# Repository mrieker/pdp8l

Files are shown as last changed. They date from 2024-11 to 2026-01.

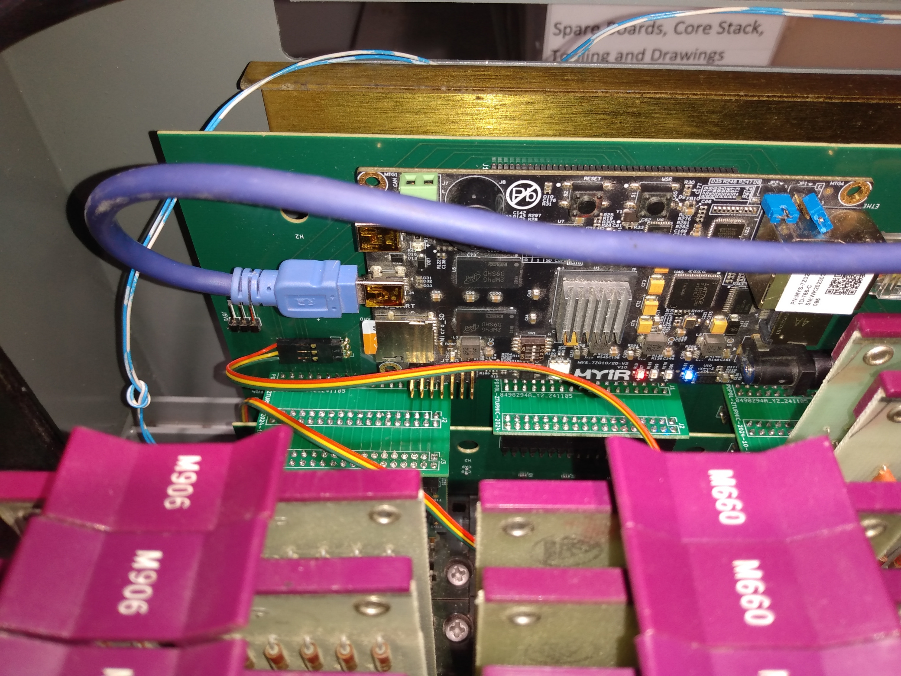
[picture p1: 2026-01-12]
pics/zturn-boards-installed-sideview.jpg

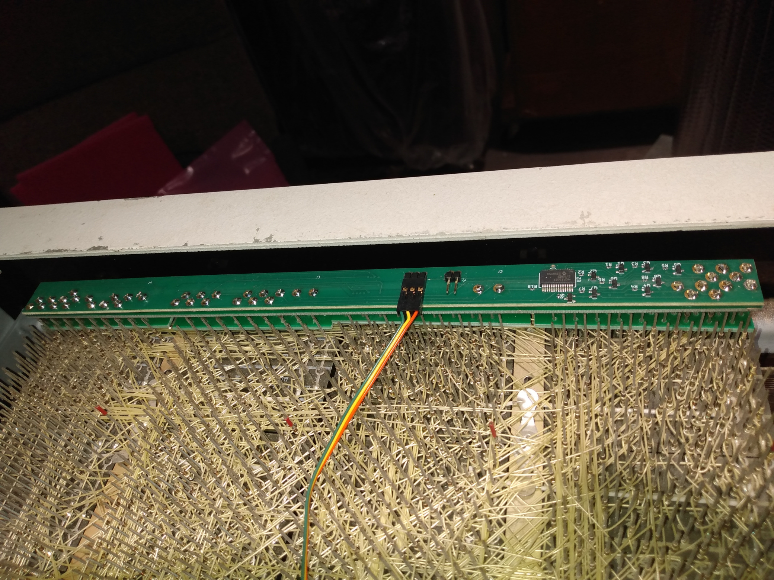
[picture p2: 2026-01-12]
pics/pcb4-installed-on-backplane.jpg

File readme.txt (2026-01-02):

PDP-8/L related projects

* automated front-panel replacement
    raspberry-pi based circuit board plugs in front slot
    raspi program runs TCL scripts to load and run tests (maindec and otherwise)

    pipan8l/pcb - circuit board
    pipan8l/pipan8l - raspi program
        provides TCL commands to access light & switch signals

* automated front-panel overlay
    I2C based circuit board piggy-backs onto row 1 of backplane with real panel plugged into slot 1
    connects to zturn board plugged into row 36 via 3-wire I2C cable
    zturn program runs TCL scripts to load and run tests (maindec and otherwise)

    pipan8l/pcb3 - circuit board (through hole parts)
    pipan8l/pcb4 - circuit board (surface mount parts)
    pipan8l/z8lpanel - zturn program
        provides TCL commands to access light & switch signals
            senses lights and switches
            can also override switches for automated testing and booting

* expansion box replacement
    zynq/zturn-7020 based circuit board set (4) plugs in rear slots
    provides functionality of 28KW extended memory, rk05, tc08, ttys, vc8 i & e
    can also provide base 4KW memory or use real PDP-8/L 4KW core
    can run with real PDP-8/L or can simulate the PDP-8/L for development

    pipan8l/z8l* - various zynq programs
        with real PDP-8/L only
            z8lreal - set fpga to real (non-simulation) mode
            z8lpanel - access front panel overlay board
                provides TCL commands to access real pdp light & switch signals
                can override or just sense real switches
        with zynq PDP-8/L simulator only
            can run on zturn board by itself or with all boards plugged into real pdp
            z8lsim - set fpga to simulation mode
                provides TCL commands to access simulated light & switch signals
            z8ltrace - print simulation instruction trace
        runs with either real or simulated PDP-8/L
            z8lcmemtest - test dma access to PDP-8/L core and zynq fpga memories
            z8ldump - dump zynq registers
            z8lmctrace - print memory cycle trace
            z8lrk8je - access RK05 disk drives
            z8lsimtest - test PDP-8/L processor with random instructions and data
            z8ltc08 - access TU56 tape drives
            z8ltty - access tty 03,40,42,44,46 lines
            z8lvc8 - access VC8 I & E
            z8lxmemtest - test extended memory

    zturn/zturn{34b,34d,35,36} - circuit boards for rear slots
    zturn/zturnic - interconnects the three boards (3 needed)
    zynq - zynq fpga code
    zplin - zynq petalinux

    see quickstart.txt for example programs

* repo directories

    edu20c - edusystem basic
    edu25r - edusystem basic
    music - music program (also boots OS/8)
    zturn - various zturn circuit boards (plug into slots 34,35,36 of PDP-8/L)
            needed for I/O emulation
    zplin - zynq petalinux files
            needed to rebuild linux kernel for zturn board
    zynq - fpga source files

    pipan8l - C++ programs that run on a RasPI or ZTurn

    pipan8l/km-* - various kernel modules needed by the RasPI and ZTurn programs

    pipan8l/pcb - front-panel replacement board for console automation only
            through-hole parts
            use with RasPI (no I/O device emulation)

    pipan8l/pcb3 - front-panel backplane overlay board
            through-hole parts
            use with ZTurn for console automation and I/O device emulation
            build pipan8l programs with 'make FPPCB=3'

    pipan8l/pcb3x - front-panel backplane pin spacer/pin alignment board

    pipan8l/pcb4 - front-panel backplane overlay board
            surface-mount parts
            use with ZTurn for console automation and I/O device emulation
            build pipan8l programs with 'make FPPCB=4'

    pipan8l/pdp8v - link to PDP-8/V repo for assembler and linker programs

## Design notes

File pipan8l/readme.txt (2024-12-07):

The pipan8l program runs on a RasPI-Zero-W plugged into the pcb that
is then plugged into slot 1 of the PDP-8/L replacing its front panel.

RasPI-Zero-W uses /dev/i2c-1 to access the I2C bus going to the PCB.
Any RasPI that runs recent RasPI OS and has a 40-pin GPIO connector
should work, but I use a RasPI Zero because it is small, allowing me
to flip the processor over without any issue.

Here is a pic of everything running:

    https://www.outerworldapps.com/pdp8l-with-pipan8l.jpg

The PIPAN8L board is in the lower right corner plugged into the 8/L downside-up.
The PC screen on the left shows the pipan8l program on the lower terminal window
testing memory, with pipan8l -status running on the upper terminal window
continuously showing the status of the lights and switches

- - - - - - - - - - - - -

The PCB plugs into slot 1 of the PDP-8/L in place of the console.

    RasPI-Zero-W ./pipan8l  ==>  PCB MCP23017s  ==>  PDP-8/L slot 1  ==>  rest of PDP-8/L

The RasPI can be powered from its own USB cable or from the PDP's 5V supply.
To power it from the PDP, install the jumper on the right end of the PCB.
I use the USB power so I can turn the PDP off and the RasPI will not need rebooting.

BE SURE TO USE 1.4mm THICK PCB STOCK.  1.6mm WON'T FIT.  The Digital spec says
board thickness of their modules is 0.056", which is a hair thicker than 1.4mm.
Even at 1.4mm, it takes a little gentle tapping to get it plugged in, so maybe
1.2mm might be better.  But even Digital's modules can be tough to insert.

I've used 1.2mm on the zturn36 board and it seems to work and is still firm but fairly
easy to insert.

- - - - - - - - - - - - -

./pipan8l runs the test program.  (You can type ./pip then press tab).
It reads commands from the prompt and can run scripts written in TCL.
The commands echo the switches and lights:

    setsw <switchname> <value>      - sets switch to a value
    getsw <switchname>              - gets value of a switch
    getreg <registername>           - gets value of a register (light bulbs)

And there is a command used to flush series of setsw commands:

    flushit                         - writes out any pending switch changes to MCP23017s
                                    - sets up to read MCP23017s when needed

There are a couple utility commands:

    ctrlcflag                       - sense if control-C has been pressed, optionallly clearing it
                                    - used for test scripts
                                    - otherwise, two control-Cs will abort out of pipan8l

    assemop <mnemonic> <operand>    - assemble the given assembly language instruction
    disasop <opcode>                - disassemble the given opcode to assemly language

And the pipan8lini.tcl script adds some higher-level commands:

    assem <address> <mnemonic> <operand>    - assemble the instruction and deposit in memory
    disas <start> <stop>                    - disassemble the instructions in given memory range
    dumpit                                  - print out all registers and switches
    flicksw <switchname>                    - flick the given switch on then off
    loadbin <filename>                      - load the given bin file into memory
    octal <value>                           - print the given value as 4-digit octal number
    rdmem <address>                         - read memory location
    startat <address>                       - does load address followed by start
    stepit                                  - do a single step then dump switches & lights
    wrmem <address> <value>                 - write the given value to memory

Note:
    The command processor is a TCL interpreter, so all numbers default to decimal.
    Prefix numbers with a 0 if you want to input an octal number.
    Use the octal command to convert number to octal for printing.

So when it's all running, you can do commands like:

    ./pipan8l               ;# start it running
    assem 0200 isz 030      ;# input a simple test program
    assem 0201 jmp 0200
    assem 0202 iac
    assem 0203 jmp 0200
    disas 0200 0203         ;# print it out to verify it
    startat 0200            ;# start it running
    flicksw stop            ;# stop it wherever it is
    setsw step 1            ;# turn on the step mode switch
    stepit                  ;# single cycle and print lights & switches
    stepit
    stepit                  ;# ... 3 times
    setsw step 0            ;# turn single cycle off
    flicksw cont            ;# continue
    dumpit                  ;# see it running
    dumpit
    flicksw stop            ;# stop processor so we can access memory
    octal [rdmem 030]       ;# read the counter and print in octal
    startat 0200            ;# restart program

Logged into RasPI:

$ sudo apt install tcl-dev
$ make
    ...
$ ./pipan8l

          ST=F  AC=0.7777 MA=0.7240 MB=7777 IR=7  OPR  SR=0000 DFLD IFLD MPRT STEP

TCL scripting, do 'help' for pipan8l-specific commands
  do 'exit' to exit pipan8l
pipan8l> assem 0200 isz 030
pipan8l> assem 0201 jmp 0200
pipan8l> assem 0202 iac
pipan8l> assem 0203 jmp 0200
pipan8l> disas 0200 0203
0200  2030  ISZ   0030
0201  5200  JMP   0200
0202  7001  IAC
0203  5200  JMP   0200
pipan8l> startat 0200
pipan8l> flicksw stop
pipan8l> setsw step 1
pipan8l> stepit
          ST=E  AC=0.0000 MA=0.0030 MB=0000 IR=2  ISZ  SR=0203 DFLD IFLD MPRT STEP
pipan8l> stepit
          ST=F  AC=0.0000 MA=0.5027 MB=5747 IR=2  ISZ  SR=0203 DFLD IFLD MPRT STEP
pipan8l> stepit
          ST=F  AC=0.0000 MA=0.0200 MB=2577 IR=5  JMP  SR=0203 DFLD IFLD MPRT STEP
pipan8l> setsw step 0
pipan8l> flicksw cont
pipan8l> dumpit
  RUN     ST=F  AC=0.0003 MA=0.4230 MB=5755 IR=3  DCA  SR=0203 DFLD IFLD MPRT
pipan8l> dumpit
  RUN     ST=E  AC=0.0005 MA=0.0100 MB=4177 IR=2  ISZ  SR=0203 DFLD IFLD MPRT
pipan8l> dumpit
  RUN     ST=F  AC=0.0006 MA=0.0233 MB=0560 IR=3  DCA  SR=0203 DFLD IFLD MPRT
pipan8l> flicksw stop
pipan8l> octal [rdmem 030]
4521
pipan8l> startat 0200
pipan8l>

- - - - - - - - - - - - -

It is somewhat tedious to keep entering dumpit commands to see what the panel is doing.
So pipan8l can be passed the -status option, and it will continuously dump the panel
contents in similar format to the actual PDP-8/L panel:

  PDP-8/L       -   - - -   - * -   - * *   - * -  0.0232  MA   IR [ - * *  DCA ]           1804 fps

                    * - -   * - *   * - *   - * -    4552  MB   ST [ f E d wc ca b ]

                -   - - -   - * *   - * -   - * -  0.0322  AC   ion per prt RUN

  MPRT  DFLD IFLD   - - -   - * -   - - -   - * *    0203  SR   ldad  start cont stop step exam  dep

Capital letters indicate the light is ON.
Small letters incdicate it is off.
Also, the ON lights are highlighted in green.

Leave pipan8l running in one terminal window of the RasPI.

Then, you can either run pipan8l -status from another terminal window of the RasPI:

    ./pipan8l -status

Or you can run it from a terminal window of a PC:

    ./pipan8l -status <ip-address-of-raspi>

It does UDP to the pipan8l program to read the panel state as fast as it can.

- - - - - - - - - - - - -

There is a simple memory test script, testmem.tcl.
To use it:

    ./pipan8l

    source testmem.tcl

    testzeroes 0 077            ;# test writing zeroes to memory 0000..0077
                                ;# writes then verifies

    testrands 0100 0177         ;# writes random numbers to 0100..0177 then verifies

    looptest testrands          ;# writes random numbers to 0000..0037 then verifies
                                ;#  then does 0040..0077 and verifies
                                ;#  then does 0100..0137 and verifies
                                ;#      ...
                                ;#  all the way through to 7740..7777
                                ;#  then repeats forever

Note:
    These tests run by simulating deposit and examine console operations so do not require that
    the processor be able to run a program.  It is just like someone manually doing load address,
    deposit and examines, flicking switches and reading lights, but it's all automated.

    The PDP-8/L circuitry limits the rate of panel operations (load address, examine, deposit, etc)
    to about 10 per second (for switch debouncing).  So these tests run S-L-O-W-L-Y.  But it beats
    doing it by hand!

$ ./pipan8l

TCL scripting, do 'help' for pipan8l-specific commands
  do 'exit' to exit pipan8l
pipan8l> source testmem.tcl

  looptest - wrap one of the below test to run continuously
  testzeroes [beg [end]] - writes zeroes to all memory then verifies
  testones [beg [end]] - writes ones to all memory then verifies
  testrands [beg [end]] - writes randoms to all memory then verifies

pipan8l> looptest testrands

PASS 1

write randoms 0000..0037...
 0000
verify randoms...
 0000: 5476       0453       6021       3630       3042       7403       7603       7006      
 0010: 6343       2240       0554       5052       6070       4357       0443       1714      
 0020: 4525       2447       5673       5475       5153       7647       4334       4777      
 0030: 3427       5527       0065       0560       4074       4412       6431       2176      
write randoms 0040..0077...

verify randoms...
 0040: 6633       5621       7064       6502       4116       5460       6045       5404      
 0050: 2353       3512       1610       4655       7162       1455       0204       2604      
 0060: 6124       4103       6756       5633       3630       1045       0376       2535      
 0070: 6567       0310       5311       3551       4376       6131       6133       2620      
write randoms 0100..0137...
 0100
verify randoms...
 0100: 7356       6277       7265       5057       4612       2453       7610       5016      
 0110: 2501       1631       1034       3662       6530       6421       7232       5563      
 0120: 6133       7601       2607       0475       5310       1223       0230       0133      
 0130: 3302       1425       2162       0576       5154       3105       0162       0132      
write randoms 0140..0177...

verify randoms...
 0140: 6554       3664       2233       0117       0740       4636       3725       7377      
 0150: 7375       3102       3445       3022       6025       4306       6576       4673      
 0160: 2404       7613       1611       3307       2613       1267       3407       2102      
 0170: 1546       5553       2043       5753       4444       0007       6152       2125      
write randoms 0200..0237...

Here is example output with a broken memory:

verify randoms...
 0000: 7732       5502       0231!=1771 7464       3560       1064       5730       2377      
 0010: 7375       4246       1242!=1666 3224       4575       1537       3413       1176      
 0020: 7073       3573       0006!=1027 1612       0216       0744       2370       3205!=3204
 0030: 1007       5501       2044!=7144 7655       5171       6066       3023       2437      
 0040: 6355       4405       2353!=2757 6220       0563       6101       7601       6625      
 0050: 7147       3323       2014!=3614 3347       4360       5405       2725       0326      
 0060: 6773       6361!=2360 2757!=0714 7663       6745       6574       4167       0760      
 0070: 3444       2046       1104!=3104 2461       1606       7437       2360       4746      
 0100: 2425       0710       4006!=7327 0163       6610       7104       2370       3022      
 0110: 0246       1307       2014!=3515 3146       7261       0212       1023       5405      
 0120: 1526       1515       4102!=4123 3770       1405       0464       3416       2317!=2316
 0130: 0432       2531       5246!=5756 0713       4227       5537       0561       7164      
 0140: 0735       7736       0110!=3314 0066       5141       0377       6707       4753      
 0150: 6760       6203       1025!=3025 3551       5451       5634       7334       4476      
 0160: 7416       6567!=4567 7757!=7756 1442       7417       2605       1020       6734      
 0170: 3106       1414       0137!=0537 5142       2133       2045       3725       4332      
 0200: 3162       1570       0000!=0212 5752       3554       1153       4414       1204      
 0210: 3345       2605       0000!=3200 0417       5403       0227       1676       3160      
 0220: 5074       2470       0006!=6617 2367       3341       3555       5204       2455      
 0230: 1016       5226       2401!=2621 6533       3131       7554       1325       1741      
 0240: 6507       0162       0001!=2373 5762       1014       6243       7537       1353      
 0250: 7167       2177       0020!=0023 4406       7050       0275       0236       5150      
 0260: 7351       5001!=5000 4651!=4251 1177       1361       5122       6003       2647      
                                    ^ shorted diode                                        ^ bad inhibit driver resistor
                         ^ shorted diode

- - - - - - - - - - - - -

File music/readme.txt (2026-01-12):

setup os/8 disk:

    ./setup-os8.sh      just once or to start over

boot os/8 disk:

    ./manual.sh real    using real pdp
    ./manual.sh sim     using simulator

compile music.pa (just once after doing setup-os8.sh):

    on another screen do: ./ldptr.sh music.pal

    then back on os/8 screen, press enter at ^ prompt:

        .R PIP
        *MUSIC.PA<PTR:
        ^

    press enter and tape reads in, then press control-C at * prompt:

    then you get . prompt:

        .PAL MUSIC,RKB0:MUSIC<MUSIC  (creates listing file, takes about 90 sec)
          or
        .PAL MUSIC<MUSIC             (no listing file, takes about 30 sec)

        .LOAD MUSIC
        .SAVE SYS MUSIC=2401         (creates SYS:MUSIC.SV file)

list music files and play something:

    .DIR RKB0:*.MU

    .R MUSIC
    *RKB0:FIFTH1
    (takes 5..10 sec then starts)
    control-Q to quit whatever it is playing and get * prompt for another file to play

to convert a midi file (4 tracks max):

    ./readmidi < somefile.midi > somefile.mu.txt
    ./ldptr.sh somefile.mu.txt

    .R PIP
    *RKB0:SOMEFL.MU<PRT:
    ^ enter
    * control-C

to hear music:

    real pdp only:
        tune radio 600..700kHz placed near backplane with cover off

    real pdp or sim (zturn plugged into pdp backplane with real pdp turned on):
        hook wire from D36-B2 backplane to amplified speakers
            open-collector so needs 3K-5K pullup to +5V such as on D36-A1

    real pdp or sim (zturn plugged into pdp backplane or not):
        run '../pipan8l/z8lpbit -server &' on a Linux PC or RasPI with headphones or speaker
            adjust volume with PC/RasPI sound control panel
        run '../pipan8l/z8lpbit -sound <ipaddressofpc> &' on the zturn

    sim only (zturn not plugged into pdp backplane):
        connect wire from zturn J11-26 to amplified speakers
        3.3V totem pole, do not use a pullup

to see it counting through the music:

    ../pipan8l/z8ldump

    look for xbraddr (extended block ram address) register
    should be able to see it count up as music plays

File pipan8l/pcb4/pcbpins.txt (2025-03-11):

AA1 SW MPRT     A28
AB1 SW DFLD     A27
AC1 SW IFLD     B28
AD1 SW SR04     A26
AD2 SW SR03         A01
AE1 LT LINK     A25
AE2 SW SR02         A02
AF1 LT EMA      A24
AF2 SW SR01         A03
AH1 LT MB01     A23
AH2 SW SR00         A08
AJ1 LT MA01     A22
AJ2 LT AC00         A04
AK1 LT AC03     A21
AK2 LT MB00         A05
AL1 LT AC02     B27
AL2 LT AC01         A06
AM2 LT MA00     A07
AN2 LT MB02         B01
AP2 LT MA02         B02
AR2 LT MB03         B03
AS2 LT MA03     B26
AT2 LT MB04         B04
AU2 LT MA04     B25

BD2 LT AC04     B24
BE2 LT AC05         B05
BF2 LT MB05     B23
BH2 LT MA05         B06
BJ2 LT AC06     B22
BK2 LT AC07         B07
BL2 LT MB06     B21
BM2 LT MA06         C01
BP2 LT MA07         C02
BR2 LT MB07         C03
BS2 LT MB08     C27
BT2 LT MA08     C26
BU2 LT AC08     C25
BV2 LT AC09     C24

CD1 LT MB09     C22
CD2             C23
CE1 LT MA09     C21
CE2 SW SR09     C28
CF1 LT AC11     D27
CF2 SW SR10         B08
CH1 LT AC10     D26
CH2 SW SR08         C04
CJ1 LT MA10     D25
CJ2 SW SR07         C05
CK1 LT MB10     D24
CK2 SW SR06         C06
CL2 SW SR05         C08
CM1             D23
CM2 LT MB11         C07
CN2 LT MA11         D01
CP2 LT FET          D02
CR2 LT IR00         D03
CS2 LT ION          D04
CT2 LT PARE         D05
CU1             D22
CU2 LT EXE          D06
CV2 LT IR01         D21
CV2 LT IR01         D07

DB1             C21
DD2 LT IR02         E01
DE2 LT DEF      E27
DF2 LT PRTE         E02
DH1             E26
DH2 LT RUN          E03
DJ1             E25
DJ2 LT WCT          E04
DK2 LT CAD      E24
DL2 LT BRK          E05
DM2 SW SR11         E06
DN1 SW BNCY     E23
DN2 SW STOP     E22
DP2 SW CONT         E07
DR2 SW STRT     E21
DS2 SW LDAD         E08
DT2 SW STEP     E28
DU2 SW EXAM         D08
DV2 SW DEPO     D28

U1-1	SR00
U1-2	SR03
U1-3	SR02
U1-4	SR01
U1-5
U1-6
U1-7
U1-8
U1-21
U1-22
U1-23
U1-24	MPRT
U1-25	IFLD
U1-26	LINK
U1-27	SR04
U1-28	DFLD

U2-1	RSR04
U2-2	RDFLD
U2-3	RIFLD
U2-4	RMPRT
U2-5
U2-6
U2-7
U2-8
U2-21	SR10
U2-22	RSR09
U2-23	SR09
U2-24	RSR10
U2-25	RSR02
U2-26	RSR01
U2-27	RSR00
U2-28	RSR03

U3-1	SR06
U3-2	EXE
U3-3	SR08
U3-4	ION
U3-5	SR07
U3-6	IR01
U3-7	SR05
U3-8
U3-21	IR00
U3-22	RSR05
U3-23
U3-24	PARE
U3-25	RSR08
U3-26	RSR06
U3-27	FET
U3-28	RSR07

U4-1	LDAD
U4-2	BNCY
U4-3	CONT
U4-4	SR11
U4-5	STEP
U4-6	EXAM
U4-7	DEPO
U4-8	RSTEP
U4-21	STOP
U4-22	IR02
U4-23	PRTE
U4-24	DEF
U4-25	CAD
U4-26	STRT
U4-27	WCT
U4-28	RSR11

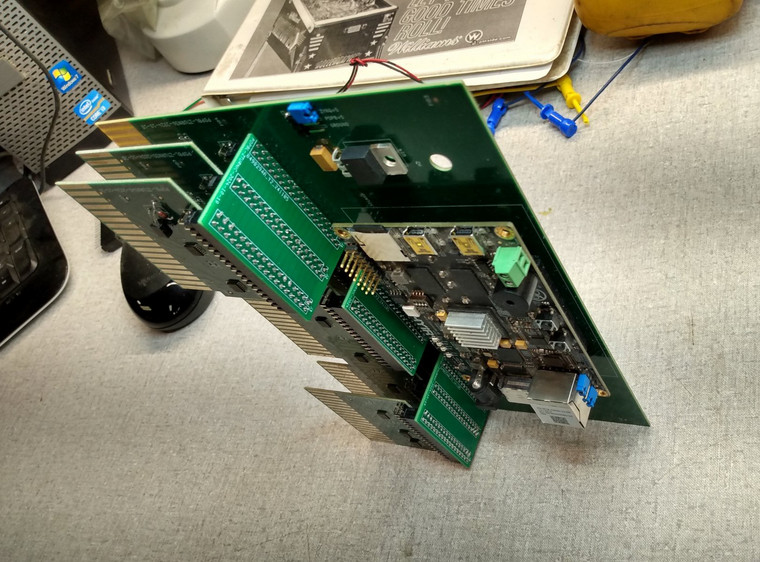
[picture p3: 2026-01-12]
pics/zturn-boards-alone.jpg

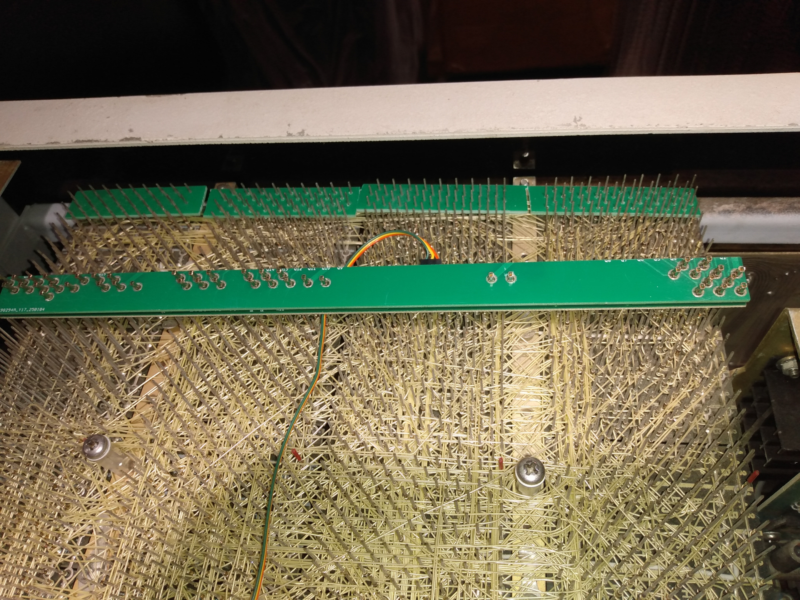
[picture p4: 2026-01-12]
pics/pcb4-removed-from-backplane.jpg

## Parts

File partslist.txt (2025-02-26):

    ZTURN36

        3) 2x18 pin 0.1" male horizontal
            https://www.digikey.com/en/products/detail/adam-tech/PH2RA-36-UA/9830520

        2) 2x40 pin 0.05" male
            https://www.digikey.com/en/products/detail/chip-quik-inc/HDR127MET80M-G-V-TH/9835079

        1) ZTurn 7020 (7010 has fewer I/O pins so won't work)
            https://www.myirtech.com/list.asp?id=502
                MYS-7Z020-C-S (no accessories) or MYS-7Z020-C (with accessories)
            accessories not strictly needed for the project but nice to have to run zturn by itself
            you will need a mini USB cable (for the console) and an ethernet cable

        2) 1x3 pin 0.1" male horizontal
            J5V1 - power jumper, 3 options:
                a) if ZTurn powered from its own USB or barrel connector, leave this empty
                   - this is useful to leave ZTurn running when PDP is turned off
                b) to power the ZTurn from the PDP8, jumper ZYNQ+5 to PDP8+5
                   - this eliminates need for ZTurn power supply
                c) power the ZTurn from some external supply using the GROUND and ZYNQ+5 pins
            JI2C1 - I2C connector going to PIPAN8L/PCB3 board
            https://www.digikey.com/en/products/detail/sullins-connector-solutions/QPC02SXGN-RC/2618262
            https://www.digikey.com/en/products/detail/w%C3%BCrth-elektronik/61300611021/4846832

        R1 - omit (pullup for B36-V1 spare zynq-to-pdp)
        R2 - omit (pullup for D36-B2 spare zynq-to-pdp - currently sound output)
        R4 - omit (pullup for I2C clock but can go on front panel board)
        R5 - omit (pullup for I2C data but can go on front panel board)

    ZTURN35

        3) 2x18 pin 0.1" male horizontal
            https://www.digikey.com/en/products/detail/adam-tech/PH2RA-36-UA/9830520

        R1 - required 1K 1/8W pullup for _EMA zynq-to-pdp

    ZTURN34D

        1) 2x18 pin 0.1" male horizontal
            https://www.digikey.com/en/products/detail/adam-tech/PH2RA-36-UA/9830520

        R3 - required 1K 1/8W pullup for B_RUN pdp-to-zynq
        C1 - 0.1uF 10V

    ZTURN34B

        1) 2x18 pin 0.1" male horizontal
            https://www.digikey.com/en/products/detail/adam-tech/PH2RA-36-UA/9830520

    ZTURNIC (3 needed, 2 with 3 connectors, 1 with 2 connectors)

        8) 2x18 pin 0.1" female
            https://www.digikey.com/en/products/detail/te-connectivity-amp-connectors/1-534998-8/291352

    PIPAN8L/PCB3

        J6 - 1x2 pin 0.1" male horizontal
             jumper for +5 to power MCP23017s from PDP
            https://www.digikey.com/en/products/detail/sullins-connector-solutions/QPC02SXGN-RC/2618262

        J7 pins 13,14,15 - 1x3 pin 0.1" male horizontal
                           I2C connector to go to ZTURN36 board
            https://www.digikey.com/en/products/detail/w%C3%BCrth-elektronik/61300611021/4846832

        43) backplane connector pins
            https://www.digikey.com/en/products/detail/te-connectivity-amp-connectors/1-104480-3/1125620

        Q1-Q16 - 2N3906 TO-92
            https://www.digikey.com/en/products/detail/onsemi/2N3906BU/1414

        U1-U4 - MCP23017 DIP package
            https://www.digikey.com/en/products/detail/microchip-technology/MCP23017-E-SP/894272

        C2,C3,C4,C5 - 0.1uF 10V
        C6 - 10uF 10V
        R22, R23, R24 - 2.2K 1/8W
        R1-R16 - 4.7K 1/8W

    Also needed is a 3-wire cable with 0.1" female header ends for the I2C going between
    the ZTURN36 board and the front panel piggy back board.  30" long is plenty.

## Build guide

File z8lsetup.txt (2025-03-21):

= = = = = = = = = = = = = = = =

Setting up the software and test software on simulator
Requires a ZTurn 7020 board but does not need to be plugged into PDP

    1) make SD card using procedure in zplin/quicksdcard.txt
       do not need to plug zturn into pdp-8/l yet

       there are BOOT.BIN and image.ub files in the zynq directory
       to copy to the SD card /boot directory

       there is a copy of the linux kernel headers in the zplin directory
        ...that are needed to build the kernel module

       the basic outline is (all done on a PC):
        1) put RasPI OS on an SD card
        2) delete all RasPI /boot files then replace with BOOT.BIN and image.ub
        3) expand rootfs partition to fill SD card
        4) edit SD card /etc/passwd to remove root and pi passwords
        5) put linux kernel headers on SD card /usr/src and link to /lib/modules

    2) plug USB cable from connector right next to the SD card on ZTurn card to a PC
       ...this is the console
       use a com port program to access the serial port at 115,200 baud

    3) log in as root to set up network and install some utilities
       - look for apt installs in zplin/quicksdcard.txt
       - enable ssh daemon and set passwords so ssh will work

    4) use ssh to log into the ZTurn as non-priv user (pi)
       optionally copy PC's .ssh/id_rsa.pub to ZTurn's .ssh/authorized_keys using scp so you don't need password any more
       clone the repo either from the PC or from github

        git clone https://github.com/mrieker/pdp8l.git

    5) download some maindec files

        cd pdp8l
        wget https://pdp8online.com/ftp/software/paper_tapes/tapes.tgz
        tar xzvf tapes.tgz

        ...should create a directory called alltapes

        wget https://so-much-stuff.com/pdp8/tapes/maindec/maindec-08-d3ra-pb -O alltapes/d3ra-pb.bin

    6) compile the software on the ZTurn

        cd pipan8l
        make FPPCB=3    have the through-hole part front panel board
        make FPPCB=4    have the surface-mount part front panel board

    7) should be able to run a couple maindecs on simulator:

        ./z8lsim run-d01b.tcl
        ./z8lsim run-d02b.tcl

    8) compile and run demo programs on simulator:

        git clone https://github.com/mrieker/pdp8v.git
        cd pdp8v/asm
        make
        cd ../..

        ./z8lsim doubleroll.tcl
        - uses './z8lsim -status' to display ascii-art front panel
        - MA & AC lights roll in opposite directions
        - press control-C to abort

        ./z8lsim kaleid.tcl e
        - displays random patterns in simulated VC/8E X window
        - close X window or press control-C to abort
        - have to use ssh -X from PC so it can open window

    9) run music program on simulator

        cd ../music
        more readme.txt
        - follow instructions therein

= = = = = = = = = = = = = = = =

Getting it to work on real PDP-8/L:

    1) plug all circuit boards in, including front panel piggy back
       should put power jumper plug on front panel piggy back board
       zturn36 board should not have a power jumper because the console usb will supply power

       Note:
        You will need to remove boards from rows 31,32,33 to get these boards
        plugged in.  Then plug them back in, subject to the TTY note below.

        Be very careful when plugging in the interconnect connectors, it is very
        easy to be off-by-one.  Maybe use a dental mirror to inspect before
        powering on.

        Likewise it is very easy to be off-by-one when plugging the ZTurn card
        into the ZTURN36 board with those finely spaced pins so be sure they are
        in correctly before powering on or it might fry some Zynq chip driver
        transistors.  And make sure the ethernet connector is where the ZTURN36
        board says ETHERNET.

       Note:
        The test programs use the TTY circuits in the FPGA to access TTY input/
        output so you must remove the TTY boards M706 and M707.  You can also
        remove the TTY clock gen card M452 and TTY cable card W076.

        When not running tests, such as when running OS/8, the FPGA TTY can be
        accessed using the ./z8ltty command.  Or you can plug the TTY boards
        back in and use them.

    2) hook up ethernet and console USB cables to the ZTurn

       Note:
        If the ZTurn has a static IP address, you should not need the USB cable
        except to power the ZTurn board.  Alternatively, the ZTurn can be powered
        from the PDP via the power jumper on the ZTURN36 board.  It is probably
        not a good idea to have both the USB cable connected and the power jumper
        in place at the same time.

    3) should still be able to log in just as before and simulator should still work

    4) turn PDP-8/L on

    5) from pdp8l/pipan8l directory

    * Test I2C connection to front panel

        ./i2cztest
        - press control-C to abort

    * Run basic memory test (analogous to toggling various locations via front panel switches):

        ./z8lreal                       # make sure accessing real PDP (not sim)

        ./z8lpanel                      # access front panel piggy-back board for automated testing

        ;# these commands override the real switches to do ldad, exam, dep to access single memory locations
        ;# should see lights blink as each deposit/examine is done
        ;# processor must be halted for them to work (just like doing ldad, exam, dep from front panel)
        ;# ...and should remain halted throughout

        z8lpanel> wrmem <addr> <data>   ;# write <data> to memory at <addr> (it's TCL so need leading 0 for octal)
        z8lpanel> octal [rdmem <addr>]  ;# read memory at <addr> then display in octal

            ;# they can be scripted, eg, to repeatedly write 5432 to mem addr 12345 until control-C:
            z8lpanel> while {![ctrlcflag]} {wrmem 012345 05432}
            ;# ... then you can trace through with a scope

            Note:
                The rdmem and wrmem commands can only access addresses 000000..017777 because the PDP-8/L
                panel only has switches for that address range.

        ;# access some memory test scripts (they use rdmem, wrmem to access memory)

        z8lpanel> source testmem.tcl

        ;# tests use console deposit/examine so they run s-l-o-w-l-y
        ;# press control-C once to abort a test back to z8lpanel> prompt
        ;# ... twice quickly should get to shell prompt

        z8lpanel> testzeroes 0 077      ;# writes 0s to locations 0000..0077 then verifies (use other ranges as needed)
        z8lpanel> testones 0 077        ;# writes 1s to locations 0000..0077 then verifies (use other ranges as needed)
        z8lpanel> looptest testrands    ;# writes random numbers to memory then verifies, in blocks of 64 words at a time

        z8lpanel> isziactest            ;# puts a simple ISZ/IAC loop in memory
        z8lpanel> startat 020           ;# start it running
                                        ;# should see link,accumulator incrementing on front panel
        z8lpanel> octal [getreg ac]     ;# read AC via D connectors at back of PDP then display in octal
        z8lpanel> dumpit                ;# dump all front panel values, observe RUN indicator
        z8lpanel> flicksw stop          ;# stop the test (optional), or use front panel stop switch
        z8lpanel> dumpit                ;# dump all front panel values, RUN indicator absent
        z8lpanel> exit

      Note:
        The above tests are generally sufficient to see if the PDP is working.  The memory tests
        will find stuck memory bits and stuck MA/MB register bits, and isziactest will test that
        the processor can execute instructions and that the AC does not have stuck bits.

      Note:
        Run './z8lpanel -status' from another ssh window to see an ascii-art replica of
        the front panel continuously updated while running the above tests.  It should
        match what the real PDP lights are showing.  If not, there is a problem, might
        be as simple as a burnt out bulb.  The AC,MA,MB,RUN,BREAK signals are read from
        the row 34,35,36 connectors at the back so that might be another source of error.

        The switch register will be different because the tests tell z8lpanel to
        override the real switches.  In any case, './z8lpanel -status' will show what
        the PDP actually sees for switches.  Use the 'relsw all' command in z8lpanel
        to release its override of the switches.  Using 'setsw sr 01234' tells z8lpanel
        to override the switchregister switches with 1234.

      Note:
        The above tests also work with z8lsim (although much faster).

      Note:
        If your core memory has issues, the FPGA can handle the core functionality.
        Instead of './z8lreal' command, use './z8lreal -enlo4k' (enable low 4K FPGA memory).
        The FPGA will tell the PDP to use FPGA RAM for all memory accesses by holding _EA low.
        You can verify enlo4k mode with either './z8ldump -once' from shell or
        'pin get xm_enlo4k' from within z8lpanel.

        You can also turn it on from within z8lpanel with 'pin set xm_enlo4k 1'
        and turn it off with 'pin set xm_enlo4k 0'.  Processor should be halted
        while using these commands!  Try 'hardreset' command if PDP gets jammed
        up somehow.

    * Test ZTurn bus connections (tests abort if they find an error):

        If your PDP does not have the DMA (BREAK) option installed,
        use the './z8lreal -nobrk' command to tell FPGA to not use
        it.  The FPGA will use internal circuitry to access its own
        RAM, even for the low 4K, instead of trying to use the PDP's
        DMA option circuitry.  This option also forces enlo4k mode
        so the processor will always use the FPGA RAM even for the
        low 4K.  This setting is also available in z8lpanel as the
        cm_nobrk pin, but you must also explicitly turn on enlo4k
        mode with pin xm_enlo4k, 'pin set xm_enlo4k 1 cm_nobrk 1'.

        memory (B) connectors - get memory address (MA) from the PDP
                                send memory read data (MEM) to the PDP
                                (write data is on MB register lines)
        dma (C) connectors - send DMA address and write data to the PDP
                             (read data is on MB register lines)
        pio (D) connectors - get memory buffer (MB) from the PDP
                             get accumulator (AC) from the PDP
                             send PIO read data (INPUTBUS) to the PDP

        test dma (C) and memory (B) connectors:
            ./z8lcmemtest
            - prints 'pass m complete n errors' (2 or 3 sec)
            - press control-C to abort

            ./z8lcmemtest -3cycle -cainc -extmem
            - tests all the bells and whistles (15 to 20 sec per pass)

            The panel lights should show a constant 5252 for MA and MB
            and that the processor is running FETCH cycles.  Theoretically
            you could see a glow of the BREAK light along with fainter
            WC and CA lights but it may not be apparent.  You can see those
            other state occasionally on the ./z8lpanel -status display when
            it happens to sample the lights at just the right time.

            Basically the processor is executing a '5252: JMP 5252' instruction
            while the z8lcmemtest program is making like it is a disk controller
            doing DMA requests via pdp8lcmem.v to read and write memory.

        test pio (D) connectors (assumes z8lcmemtest works):
            ./z8lpiotest
            - prints '*' after each pass (2 sec or so at first then every 0.5 sec thereafter)
            - press control-C to abort

            There should be a glow of activity on the front panel for
            this test as the processor is running a little program that
            can be found in z8lpiotest.cc.

        pound the living daylights out of it (originally for testing sim but adapted to test real PDP):
            ./z8lsimtest -real                      # prints every insruction
            ./z8lsimtest -real | grep '0000  L'     # prints every 10000th instruction

            You will have to get things started manually or use z8lpanel in a separate screen.
            Start the test then follow the prompt to get things going.  It waits for you to
            stop the processor, then enter the '5252: JMP 5252' loop and start it.  Either use
            the front panel directly or use z8lpanel from another ssh screen:

                ./z8lpanel
                z8lpanel> flicksw stop
                z8lpanel> setsw sr 05252
                z8lpanel> flicksw ldad
                z8lpanel> flicksw start
                z8lpanel> relsw all
                z8lpanel> exit

            It stops if there is any error.  It should run as long as you want it to.

            All lights should be flashing randomly as z8lsimtest feeds the PDP random instructions
            and operands, verifying each memory cycle as it goes along.  Also feeds in DMA cycles
            here and there (1-cycle and 3-cycle) and interrupt requests.  You shouldn't see any
            activity on the PAR,PROT lights and ION will just occasionally blink.  Also rare is for
            any of the WC,CA,B lights to blink, and RUN should be on continuously.

            Then maybe show lights in ascii-art screen while test is running:
                ./z8lpanel -status

        Note:  It is possible for these tests to leave the PDP in a wacky state when
            stopped (with control-C).  Try the 'hardreset' command in z8lpanel to try
            to unjam it, or as a last resort, power cycle the PDP.

    * Run MAINDECs:

        note:
            the loadbin function runs a lot slower on the real machine vs the simulator
            it uses deposit/examine to load the program in memory which is slow on real PDP-8/L

        ./z8lpanel run-d01b.tcl
        ./z8lpanel run-d02b.tcl
        ./z8lpanel run-d04b.tcl
        ./z8lpanel run-d05b.tcl
        ./z8lpanel run-d07b.tcl
        ./z8lpanel run-d1eb.tcl
        ./z8lpanel run-d1gb.tcl
        ./z8lpanel run-d3ra.tcl

        note:
            when running d3ra test, you may want to monitor dectape status in another
            ssh window with a './z8ltc08 -status' command (another ascii-art screen)

    * Run doubleroll, kaleidoscope and music programs as desired

        Use same instructions as for simulator except do a ./z8lreal
        command to make sure using real PDP, then use ./z8lpanel instead
        of ./z8lsim.

= = = = = = = = = = = = = = = =

    To monitor what is going on with the FPGA at any time, run the ./z8ldump program.
    It is a continuous dump of all the registers the FPGA makes available to the ARM processor.
    It can be run at any time without any side effects.
    It is often useful to leave ./z8ldump running on one window all or most of the time.
    You can do './z8ldump -once' to just display one frame.

    Sample output:

        VERSION=384C4097 8L
          oBIOP1=0             oBAC=0000                              iBEMA=1              iDMAADDR=2540     S majstate=HALT
          oBIOP2=0             oBMB=7572           nanocstep=1        i_CA_INCRMNT=1       iDMADATA=1175     I nextmajst=HALT
          oBIOP4=0             oMA=2420            nanotrigger=1      i_DATA_IN=1          iINPUTBUS=0000    M timedelay=0
          oBTP2=0                                  nanocontin=1       iMEMINCR=0           i_MEM=0205        . timestate=TSIDLE
          oBTP3=0            S lbBRK=0             fpgareset=0        i_MEM_P=1          S swCONT=0          . cyclectr=0000
          oBTS_1=0           I lbCA=0              simit=0            i3CYCLE=0          I swDEP=0           . simmemen=0
          oBTS_3=0           M lbDEF=0             bareit=0           iAC_CLEAR=0        M swDFLD=0
          o_BWC_OVERFLOW=1   . lbEA=0                                 iBRK_RQST=0        . swEXAM=0          S debounced=0
          o_B_BREAK=1        . lbEXE=0             bDMABUS=5104       i_EA=0             . swIFLD=0          I lastswLDAD=0
          oE_SET_F_SET=1     . lbFET=0             x_DMAADDR=0        iEMA=1             . swLDAD=0          M lastswSTART=0
          oJMP_JMS=0         . lbION=0             x_DMADATA=1        iINT_INHIBIT=0     . swMPRT=0
          oLINE_LOW=0        . lbLINK=0                               iINT_RQST=0        . swSTEP=0            oC36B2=0
          oMEMSTART=0        . lbRUN=0             bMEMBUS=7777       iIO_SKIP=0         . swSTOP=0            oD35B2=0
          o_ADDR_ACCEPT=1    . lbWC=0              r_MA=1             i_MEMDONE=1        . swSTART=0
          o_BF_ENABLE=1      . lbIR=2              x_MEM=1            i_STROBE=1         . swSR=0000
          o_BUSINIT=0
          oB_RUN=0           S lbAC=0000           bPIOBUS=7671       memcycctr=91D2492D   xbraddr=00000
          o_DF_ENABLE=1      I lbMA=0204           r_BAC=1            didio=0              xbrwena=0
          o_KEY_CLEAR=1      M lbMB=0337           r_BMB=0            hizmembus=1          xbrenab=0
          o_KEY_DF=1                               x_INPUTBUS=1       meminprog=   0       xbrrdat=7572
          o_KEY_IF=1           o_LOAD_SF=1                                                 xbrwdat=0000
          o_KEY_LOAD=1         o_SP_CYC_NEXT=1

        VERSION=524B2005 RK 00000000 00000000 00000000 00000000 00000001 DEADBEEF DEADBEEF

        VERSION=56432005 VC 00000000 30100000 00006996 203EBED8 DEADBEEF DEADBEEF DEADBEEF

        VERSION=4650200D FP 00000000 00000000 6B7FE97F 00F51FF2 F0009F30 00000000 DEADBEEF

        VERSION=584D202D XM  enlo4k=0  enable=1  ifld=6  dfld=6  field=6  _mwdone=1  _mrdone=1  os8zap=0,step=0
                mrhold,step=0,0  mwhold,step=0,0  xmstate= 0  xmmemenab=0  memcycctr=689F89F8.9D89F89F
                addrlatchwid=8  readstrobedel=35  readstrobewid=10  writeenabdel=75  writeenabwid=5  writedonewid=10

        VERSION=5348200C SH err=2000 foe=0 ms=F  ts=1+ 1 ir=5252 pc=5252 mb=5252 ma=5252 l.ac=0.0000 ea=5252

        VERSION=434D1018 CM 227D0560 00000020 00000000

        VERSION=54541009 TT 40000091 000000AA 00000103

        VERSION=54541009 TT 40000D5B 00000C80 00000120

        VERSION=54541009 TT 40000000 00000000 00000122

        VERSION=54541009 TT 40000000 00000000 00000124

        VERSION=54541009 TT 40000000 400006A3 00000126

        VERSION=50421004 PB 004AE000 30D30005 00000000

        VERSION=50520002 PR 00000000

        VERSION=50500001 PP 00000000

        VERSION=54430002 TC 80000000

  Top half (above the RK line):

    These signals top center are important:

        nanocontin=1        =1: FPGA is clocking itself at 100MHz (normal)
                            =0: FPGA must be clocked by setting nanotrigger (debugging)
        fpgareset=0         =0: FPGA running normally
                            =1: FPGA being held in power-on reset state
        simit=0             =0: FPGA is using real PDP-8/L (sim held in reset)
                            =1: FPGA is using simulator (ignoring PDP)
        bareit=0            =0: send simulated device signals to PDP (normal)
                            =1: send ARM debug signals to PDP (debugging)

        They can be read with ./z8lpanel 'pin get' command and written with 'pin set' command.
        The nanotrigger signal is self-clearing.

            pin set fpgareset 1 fpgareset 0     ;# blip the fpgareset signal
            pin get simit                       ;# see if simulating (prints/returns 0 or 1)
            pin set simit 1                     ;# turn on simulator (ignore PDP)

    Signals beginning with 'o' are outputs from the PDP to the FPGA.
    The names pretty much correspond with the signals in the PDP documentation.
    The ones that have o_ at the beginning are active low, the others are active high.

        oBIOP1 = I/O pulse 1 from the PDP (active high)
        o_B_BREAK = break cycle indicator from the PDP (active low)

    Signals beginning with 'i' are inputs to the PDP from the FPGA.
    The names pretty much correspond with the signals in the PDP documentation.
    The ones that have i_ at the beginning are active low, the others are active high.

        iBRK_RQST = FPGA is requesting a DMA cycle from the PDP (active high)
        i_EA = FPGA is telling PDP to use extended memory instead of core for the cycle (active low)

    Signals beginning with 'b' are the bi-directional busses, bPIOBUS (on the 'D' connectors),
    bMEMBUS (on the 'B' connectors), bDMABUS (on the 'C' connectors).  The bits are generally
    scrambled around so aren't generally useful.  The bus signals are gated between the FPGA
    and the PDP by the r_ (received into the FPGA from the PDP) and x_ (transmitted out from
    the FPGA into the PDP) signals.  Care must be taken to not enable two drivers on the same
    set of wires at the same time so the transistors don't get overloaded.

    Note:
        Active high/low of these signals may differ from the PDP-8/L signal as the signal
        may go through an inverting 3.3V/5V conversion between the FPGA and the PDP-8/L.

    Signals listed with S-I-M pertain to the simulator only.
    Those beginning with lb are lightbulbs, sw are switches.
    Others are miscellaneous state information.

  Bottom half (starting with RK line) are the device modules:
    Most are raw ARM 32-bit registers so are in hexadecimal

    RK - pdp8lrk8je.v module registers (decpack)

    VC - pdp8lvc8.v module registers (video controller)

    FP - pdp8lfpi2c.v module registers (front panel via I2C)

    XM - pdp8lxmem.v module registers (extended memory)

        of particular importance:

            enlo4k=1 : use FPGA 32KW memory for low 4K
                  =0 : real PDP-8/L : use PDP-8/L core memory for low 4K
                          simulator : use small FPGA 4KW memory for low 4K
            available to z8lpanel pin get/set command as xm_enlo4k

    SH - pdp8lshad.v module registers (processor shadow)

            monitors processor cycles to make sure they are what they should be
            sets err bits and freezes contents when discrepancy found
            works only when enlo4k enabled continuously since last START key

    CM - pdp8lcmem.v module registers (direct memory access)

            used by z8lrk8je and z8ltc08 to do dma transfers

        of particular importance:

            VERSION=434D1018 CM 227D0560 00000020 00000000
                                         ^
                                         |
                                         bit <29> = available to z8lpanel pin get/set command as cm_nobrk

            - cm_nobrk=0 : uses PDP's BREAK circuitry so can access PDP's core memory
            - cm_nobrk=1 : all accesses are made to FPGA's 32KW memory
                           must have xm_enlo4k set for it to be useful
                           otherwise PDP would be using its own core for low 4K,
                             while all low 4K DMA would be going to FPGA RAM

    TT - pdp8ltty.v module registers (teletypes)

        of particular importance:

            VERSION=54541009 TT 40000091 000000AA 00000103
                                                        ^^
                                                        ||
                                                        kb I/O port (+1 for the pr I/O port)

    PB - pdp8lpbit.v module registers (pulse bit audio)

    PR - pdp8lptr.v module registers (paper tape reader)

    PP - pdp8lptp.v module registers (paper tape punch)

    TC - pdp8ltc08.v module registers (dectape)

= = = = = = = = = = = = = = = =

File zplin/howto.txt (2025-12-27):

########################################################################
#  How to set up tools for building Zynq FPGA code and create SD card  #
########################################################################

note:
    to create an sd card with the given fpga code, follow steps in quicksdcard.txt.
    if you want to make changes to the fpga code, follow the steps below.

start with:
    always needed:
        ZTurn 7020 board
        raspberry pi os install image (32-bit lite version)
        - bookworm (debian 12) is slow, bullseye (debian 11) is fast
        - ref: https://forums.raspberrypi.com/viewtopic.php?t=6019 -- bug mentioned halfway down

    to compile FPGA code:
        ubuntu 16.04
        vivado 2018.3 installed in /tools/Xilinx/Vivado/2018.3/bin/vivado
        petalinux 2018.3 in /tools/Xilinx/Downloads/petalinux-v2018.3-final-installer.run
        ./zturn_7z020_hdmi.bsp
        ./vdmahdmi.patch

        also make sure board_files/zturn-7z020 is in place in vivado tree
            /tools/Xilinx/Vivado/2018.3/data/boards/board_files/zturn-7z020
        untar ./zturn-7z020-board-files.tgz if not there

        must use Vivado 2018.3 cuz of bsp file supplied by MYIR

##############################
#   build petalinux kernel   #
##############################

    This creates a new boot file with default FPGA code (BOOT.BIN) and kernel image (image.ub).
    You can skip this section and use the provided images in ../zynq/BOOT.BIN and image.ub.

sudo ...
    apt install tofrodos iproute gawk gcc git-core make net-tools ncurses-dev \
        libncurses5-dev tftpd-hpa zlib1g-dev flex bison lib32z1 lib32ncurses5 lib32stdc++6 libselinux1
    apt install build-essential
    apt install chrpath socat autoconf libtool texinfo gcc-multilib
    apt install libsdl1.2-dev libglib2.0-dev
    apt install openssl-dev
    apt install libssl-dev
    apt install openssl
    apt install zlib1g:i386

    dpkg-reconfigure dash      << select <No>

# https://www.instructables.com/Getting-Started-With-PetaLinux/

[[ do the whole thing from medium-sized xterm ]]

cd .../pdp8l/zplin              # ie, directory containing this howto.txt
/tools/Xilinx/Downloads/petalinux-v2018.3-final-installer.run `pwd`/petadevel   # 11m56
    q y <Enter> q y <Enter> q y <Enter>    to skip licenses

source petadevel/settings.sh
source /tools/Xilinx/Vivado/2018.3/settings64.sh

mkdir petakernl
cd petakernl
petalinux-create -t project -s ../zturn_7z020_hdmi.bsp  # 1m05
cd zturn
petalinux-config    # 1m35 (just select <Exit> at the bottom)
petalinux-build     # 5m44
petalinux-package --boot --force --fsbl ./images/linux/zynq_fsbl.elf --fpga ./images/linux/system.bit --u-boot

cd build/tmp/work-shared/plnx-zynq7/kernel-source
patch -p1 < ../../../../../../../vdmahdmi.patch
    to disable VDMA and HDMI  (don't have fpga source for hdmi stuff)

    - unpatched xilinx_vtc.c 20094 bytes
        patched xilinx_vtc.c 19220 bytes

cd ../../../../..               (ie, petakernl/zturn)

petalinux-config -c kernel
    Device Drivers --->
        DMA Engine Support --->
            Xilinx DMA Engines [off]
            Xilinx AXI DMAS Engine [off]
petalinux-build     3m36                            # let it fail to compile vdmafb.c

cd build/tmp/work-shared/plnx-zynq7/kernel-source
patch -p1 < ../../../../../../../vdmahdmi.patch     # second time
cd ../../../../..               (ie, petakernl/zturn)
petalinux-build     4m52                            # it should succeed

petalinux-build -c kernel -x compile -f             # 0m29
petalinux-build                                     # 1m57
petalinux-package --boot --force --fsbl ./images/linux/zynq_fsbl.elf --fpga ./images/linux/system.bit --u-boot
ls -l images/linux/BOOT.BIN                         # contains default FPGA code
ls -l images/linux/image.ub                         # linux kernel

if edit kernel sometime:
    petalinux-build -c kernel -x compile -f
    petalinux-build

###################
#  Set up SDCARD  #
###################

    Sets up SDCARD with the BOOT.BIN and image.ub suitable for the Zynq
    Uses raspi filesystem.

# put blank sdcard in pc, comes up as something like /dev/sda
# replace /dev/sda in the commands below with whatever the sdcard really is

df                  # see if sdcard got automounted
umount /dev/sda1    # umount if so
umount /dev/sda2 ...etc

# copy raspi sdcard image to sdcard
xzcat 2024-10-22-raspios-bullseye-armhf-lite.img.xz | dd of=/dev/sda status=progress
partprobe /dev/sda

# replace raspi kernel with zturn kernel
# - use either the BOOT.BIN,image.ub created above or use those from ../zynq directory
mkdir /x
mount /dev/sda1 /x
rm -rf /x/*
cp images/linux/BOOT.BIN /x/
cp images/linux/image.ub /x/
umount /x

# expand root partition to whole sdcard
parted /dev/sda
  resizepart 2 -1s
  quit
resize2fs /dev/sda2

# remove root and pi passwords for now
mount /dev/sda2 /x
edit /x/etc/shadow              (use whatever editor you like)
  remove * or ! from root and pi line password field

# set up hostname
echo zturn > /x/etc/hostname    (or whatever you want for hostname)
edit /x/etc/hosts
  change raspberrypi to whatever was put in /x/etc/hostname

# copy kernel source so modules will compile
mkdir -p /x/usr/src/linux-headers-4.14.0-xilinx-v2018.3
rsync -av petakernl/zturn/build/tmp/work-shared/plnx-zynq7/kernel-source/ /x/usr/src/linux-headers-4.14.0-xilinx-v2018.3
rsync -av petakernl/zturn/build/tmp/work-shared/plnx-zynq7/kernel-build-artifacts/ /x/usr/src/linux-headers-4.14.0-xilinx-v2018.3
chown root:root -R /x/usr/src

# done filling sdcard
umount /x       may take a long time to flush to sdcard (30min)
rmdir /x

############################
#  Boot ZTurn from SDCARD  #
############################

connect usb serial cable from pc to zturn (115200 baud) and use terminal program to access
insert sdcard and boot zturn
login as root (or as pi then sudo bash to get root)

on zturn:
  as root:
    raspi-config -> Interface Options -> SSH -> Yes
    passwd   to set root and pi passwords so ssh will work

    optionally set up static IP address:
      edit /etc/dhcpcd.conf
      uncomment static ip configuration section
      reboot

    apt install libreadline-dev
    apt install libx11-dev
    apt install tcl8.6-dev
    apt install git
    apt install bc

    mkdir -p /lib/modules/4.14.0-xilinx-v2018.3
    ln -s /usr/src/linux-headers-4.14.0-xilinx-v2018.3 /lib/modules/4.14.0-xilinx-v2018.3/build

    cd /usr/src/linux-headers-4.14.0-xilinx-v2018.3
    edit scripts/dtc/dtc-lexer.lex.c_shipped
      Find the line 'YYLTYPE yylloc;' and change it to 'extern YYLTYPE yylloc;'
      reference : https://lkml.org/lkml/2020/4/1/1206
    make oldconfig          # 0m38
    make prepare            # 0m31
    make modules_prepare    # 1m28

  as pi:
    git clone .../pdp8l.git
    cd pdp8l/pipan8l
    make   (may need to change -ltcl to -ltcl8.6 in the makefile)
    ./z8lsim
      if Bus error - means the BOOT.BIN has default FPGA contents so do next section
      if z8lsim> prompt - means our PDP-8/L code is loaded in FPGA
    z8lsim> source testmem.tcl
    z8lsim> looptest testrands
        ...  control-C to stop test
    z8lsim> exit

######################################
#  Put PDP-8/L FPGA file onto ZTurn  #
######################################

    make sure can do ssh root@zturn from pc

then on zturn:
    ls -l /boot should show BOOT.BIN, image.ub files

    # ls -l /boot
    total 8456
    -rwxr-xr-x 1 root root 4688040 Dec  5 22:43 BOOT.BIN
    -rwxr-xr-x 1 root root 3967676 Dec  5 22:43 image.ub

then back on pc to compile FPGA code:
    cd .../pdp8l/zynq
    /tools/Xilinx/Vivado/2018.3/bin/vivado pdp8l.xpr
        do 'Generate Bitstream' to compile verilog to .bit file
    ./makebootbin.sh        make BOOT.BIN then copy to zturn and reboot

then ssh pi@zturn and do:
    cd pdp8l/pipan8l
    ./z8lsim
      if Bus error - means the BOOT.BIN still has default FPGA contents
      if z8lsim> prompt - means our PDP-8/L code is loaded in FPGA
    z8lsim> source testmem.tcl
    z8lsim> looptest testrands
        ...  control-C to stop test
    z8lsim> exit

All Done!

#########################################
#  FYI, how to create a Vivado project  #
#########################################

Use Z-turnBoard_Tutorial_Book.pdf
    - make sure board_files/zturn-7z020 is in place in vivado tree
      eg, /tools/Xilinx/Vivado/2018.3/data/boards/board_files/zturn-7z020
    - in left column, "Create Block Design"
    - add ZYNQ7 Processing System
    - do "Run Block Automation" to define and connect DDR, FIXED_IO ports
    - interconnect clocks FCLK_CLK0 -> M_AXI_GP0_ACLK, S_AXI_HP0_ACLK
    - add any Verilog/VHDL files & add as modules to block diagram
        keep them in top-level directory so Vivado doesn't bury them
    - create hardware wrapper
        "Sources" tab
        right-click the .bd file
        select "Create HDL Wrapper"
        "Let Vivado manage..."
        OK

    - Run Synthesis, but then do "Open Synthesized Design"
        - Window -> I/O Ports
        - Scalar ports
        - make pin assignments
        - click save (floppy) button in upper left to save as constraints file

    - Run Synthesis again to use new pin assignments
    - Run Implementation
    - Generate Bitstream

    - for git, have it ignore everything except:
      - your verilog/vhdl files (keep in top-level directory)
      - your .xdc file assigning pins etc
      - your .xpr file defining the project
      - your <board>/<board>.bd file defining top-level layout
      - your <board>/hdl/<board>_wrapper.vhd file

create a new BOOT.BIN -
    source petadevel/settings.sh
    source /tools/Xilinx/Vivado/2018.3/settings64.sh
    cd petakernl/zturn
    petalinux-package --boot --force --fsbl ./images/linux/zynq_fsbl.elf --fpga ***BITFILE***.bit --u-boot

...get BOOT.BIN from images/linux, copy to /boot/BOOT.BIN of ZTurn SD card then reboot

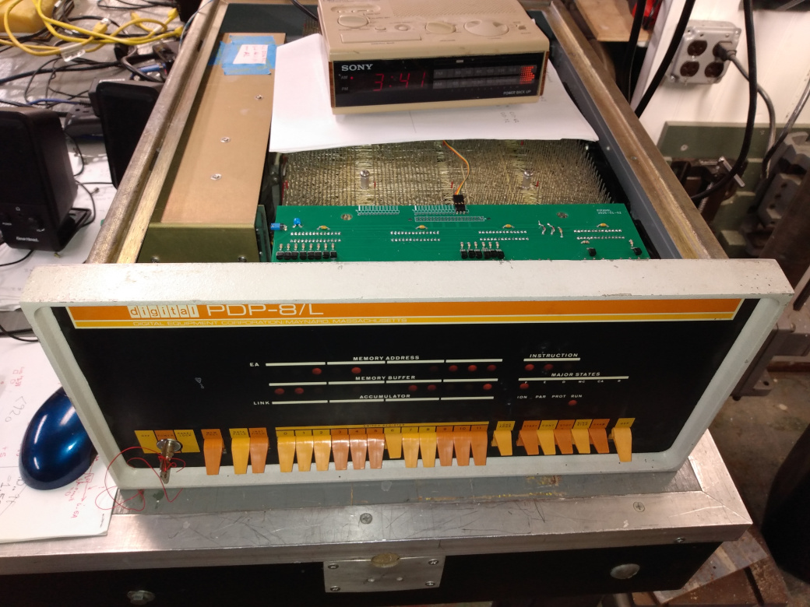
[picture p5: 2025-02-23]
pics/pcb3-installed-on-backplane.jpg

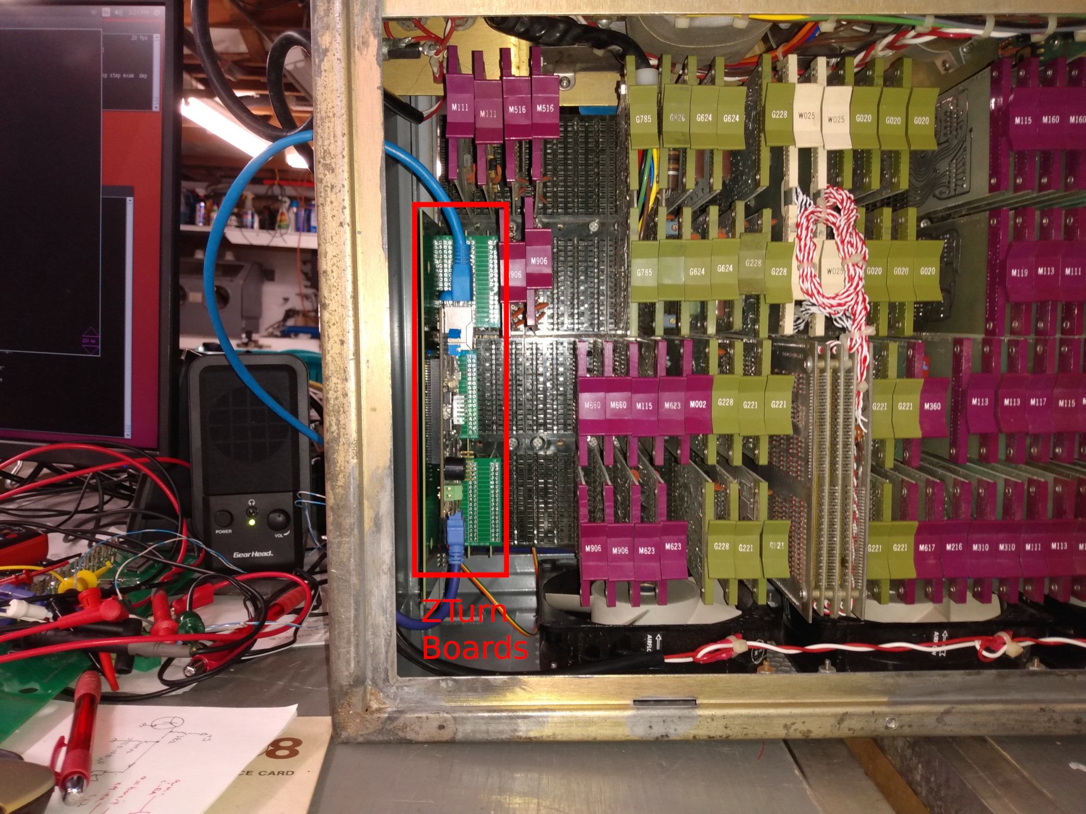
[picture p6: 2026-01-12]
pics/zturn-boards-installed-topview.jpg

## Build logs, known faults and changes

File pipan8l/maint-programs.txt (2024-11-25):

Test Listed in Maint Vol 1             z8l sim      time on real 8/L
Instruction Test 1      8I-D01B         works           20 min
Instruction Test 2      8I-D02B         works           16 min
Instruction Test 2B     08-D02A not found
Random JMP Test         08-D04B         works           3 min
Random JMP-JMS Test     08-D05B         works           4 min
Random ISZ Test         08-D07B         works           4 min
Memory Checkerboard     08-D1J0 not found
Memory Address Test     08-D1B0 not found

Extended Mem Checkbd    08-D1EB         works
Extended Mem Control    08-D1GB         works

DECtape                    D3RA         works

To run on real PDP-8/L (with pipan8l board plugged
into console and real tty wired to /dev/ttyACM0):

    stty 110 < /dev/ttyACM0
    rm -f pipan8l_ttykb pipan8l_ttypr
    ln -s /dev/ttyACM0 pipan8l_ttykb
    ln -s /dev/ttyACM0 pipan8l_ttypr
    ./pipan8l run-d01b.tcl

To run on a PC or such:

    ./pipan8l -sim run-d01b.tcl

To run on Zynq Z8L Sim (with pdp8lsim.v code loaded):

    ./z8lsim run-d01b.tcl

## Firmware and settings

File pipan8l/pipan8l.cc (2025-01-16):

//    Copyright (C) Mike Rieker, Beverly, MA USA
//    www.outerworldapps.com
//
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
//    EXPECT it to FAIL when someone's HeALTh or PROpeRTy is at RISk.
//
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
//    http://www.gnu.org/licenses/gpl-2.0.html

// access pdp-8/l front panel
// see ./pipan8l -? for options

#include <arpa/inet.h>
#include <errno.h>
#include <fcntl.h>
#include <net/if.h>
#include <netdb.h>
#include <netinet/in.h>
#include <poll.h>
#include <pthread.h>
#include <signal.h>
#include <stdint.h>
#include <stdio.h>
#include <stdlib.h>
#include <string.h>
#include <sys/socket.h>
#include <sys/time.h>
#include <tcl.h>
#include <unistd.h>

#include "assemble.h"
#include "disassemble.h"
#include "padlib.h"
#include "pindefs.h"
#include "readprompt.h"
#include "tclmain.h"

#define ABORT() do { fprintf (stderr, "abort() %s:%d\n", __FILE__, __LINE__); abort (); } while (0)
#define ASSERT(cond) do { if (__builtin_constant_p (cond)) { if (!(cond)) asm volatile ("assert failure line %c0" :: "i"(__LINE__)); } else { if (!(cond)) ABORT (); } } while (0)

struct PermSw {
    char const *name;
    int nbits;
    int pinums[12];
};

struct RegBit {
    char const *name;
    int pinum;
};

// internal TCL commands
static Tcl_ObjCmdProc cmd_assemop;
static Tcl_ObjCmdProc cmd_disasop;
static Tcl_ObjCmdProc cmd_flushit;
static Tcl_ObjCmdProc cmd_getpin;
static Tcl_ObjCmdProc cmd_getreg;
static Tcl_ObjCmdProc cmd_getsw;
static Tcl_ObjCmdProc cmd_libname;
static Tcl_ObjCmdProc cmd_readchar;
static Tcl_ObjCmdProc cmd_setpin;
static Tcl_ObjCmdProc cmd_setsw;

static TclFunDef const fundefs[] = {
    { cmd_assemop,    "assemop",    "assemble instruction" },
    { cmd_disasop,    "disasop",    "disassemble instruction" },
    { cmd_flushit,    "flushit",    "flush writes / invalidate reads" },
    { cmd_getpin,     "getpin",     "get gpio pin" },
    { cmd_getreg,     "getreg",     "get register value" },
    { cmd_getsw,      "getsw",      "get switch value" },
    { cmd_libname,    "libname",    "get library name i2c,sim" },
    { cmd_readchar,   "readchar",   "read character with timeout" },
    { cmd_setpin,     "setpin",     "set gpio pin" },
    { cmd_setsw,      "setsw",      "set switch value" },
    { NULL, NULL, NULL }
};

static int const acbits[] = { P_AC00, P_AC01, P_AC02, P_AC03, P_AC04, P_AC05, P_AC06, P_AC07, P_AC08, P_AC09, P_AC10, P_AC11, -1 };
static int const irbits[] = { P_IR00, P_IR01, P_IR02, -1 };
static int const mabits[] = { P_MA00, P_MA01, P_MA02, P_MA03, P_MA04, P_MA05, P_MA06, P_MA07, P_MA08, P_MA09, P_MA10, P_MA11, -1 };
static int const mbbits[] = { P_MB00, P_MB01, P_MB02, P_MB03, P_MB04, P_MB05, P_MB06, P_MB07, P_MB08, P_MB09, P_MB10, P_MB11, -1 };
static int const srbits[] = { P_SR00, P_SR01, P_SR02, P_SR03, P_SR04, P_SR05, P_SR06, P_SR07, P_SR08, P_SR09, P_SR10, P_SR11, -1 };

static PermSw const permsws[] = {
    { "bncy",  1, P_BNCY },
    { "cont",  1, P_CONT },
    { "dep",   1, P_DEP  },
    { "dfld",  1, P_DFLD },
    { "exam",  1, P_EXAM },
    { "ifld",  1, P_IFLD },
    { "ldad",  1, P_LDAD },
    { "mprt",  1, P_MPRT },
    { "sr", 12, P_SR11, P_SR10, P_SR09, P_SR08, P_SR07, P_SR06, P_SR05, P_SR04, P_SR03, P_SR02, P_SR01, P_SR00 },
    { "start", 1, P_STRT },
    { "step",  1, P_STEP },
    { "stop",  1, P_STOP },
    {  NULL,   0, 0 }
};

static uint16_t const wrmsks[P_NU16S] = { P0_WMSK, P1_WMSK, P2_WMSK, P3_WMSK, P4_WMSK };

static bool rdpadsvalid;
static bool wrpadsdirty;
static PadLib *padlib;
static pthread_mutex_t padmutex = PTHREAD_MUTEX_INITIALIZER;
static uint16_t rdpads[P_NU16S];
static uint16_t wrpads[P_NU16S];

static uint16_t getreg (int const *pins);
static void setpin (int pin, bool set);
static bool getpin (int pin);
static void flushit ();
static int showstatus (int argc, char **argv);
static void *udpthread (void *dummy);




int main (int argc, char **argv)
{
    if ((argc >= 2) && (strcasecmp (argv[1], "-status") == 0)) {
        return showstatus (argc - 1, argv + 1);
    }

    setlinebuf (stdout);

    bool simit = false;
    char const *logname = NULL;
    int tclargs = argc;
    for (int i = 0; ++ i < argc;) {
        if (strcmp (argv[i], "-?") == 0) {
            puts ("");
            puts ("  ./pipan8l [-log <logfile>] [-sim] [<scriptfile.tcl>]");
            puts ("     access pdp-8/l front panel");
            puts ("     -log : record output to given log file");
            puts ("     -sim : access c-module simulator");
            puts ("            invoke via ./pipan8l script");
            puts ("            runs on pc, raspi, zturn");
            puts ("            only has internal tty");
            puts ("            does not need to be plugged into pdp");
            puts ("     ...otherwise access real pdp front panel");
            puts ("            invoke via ./pipan8l script");
            puts ("            runs on raspi only");
            puts ("            has all devices that are in pdp, including zturn if plugged in");
            puts ("            must be plugged into pdp via pipan8l pcb");
            puts ("     <scriptfile.tcl> : execute script then exit");
            puts ("                 else : read and process commands from stdin");
            puts ("");
            puts ("  ./pipan8l -status [<hostname-or-ip-address-of-pipan8l>]");
            puts ("     display ascii-art front panel operated by one of the above pipan8l methods");
            puts ("     invoke via ./pipan8l script");
            puts ("     runs on pc, raspi, zturn");
            puts ("     <hostname-or-ip-address-of-pipan8l> defaults to localhost");
            puts ("");
            return 0;
        }
        if (strcasecmp (argv[i], "-log") == 0) {
            if ((++ i >= argc) || (argv[i][0] == '-')) {
                fprintf (stderr, "missing filename after -log\n");
                return 1;
            }
            logname = argv[i];
            continue;
        }
        if (strcasecmp (argv[i], "-sim") == 0) {
            simit = true;
            continue;
        }
        if (argv[i][0] == '-') {
            fprintf (stderr, "unknown option %s\n", argv[i]);
            return 1;
        }
        tclargs = i;
        break;
    }

    padlib = simit ? (PadLib *) new SimLib () : (PadLib *) new I2CLib ();
    padlib->openpads ();
    // initialize switches from existing switch states
    padlib->readpads (rdpads);
    for (int i = 0; i < P_NU16S; i ++) wrpads[i] = rdpads[i];

    // create udp server thread
    {
        pthread_t udptid;
        int rc = pthread_create (&udptid, NULL, udpthread, NULL);
        if (rc != 0) ABORT ();
    }

    // process tcl commands
    return tclmain (fundefs, argv[0], "pipan8l", logname, getenv ("pipan8lini"), argc - tclargs, argv + tclargs);
}




// assemble instruciton
//  assemop [address] opcode
static int cmd_assemop (ClientData clientdata, Tcl_Interp *interp, int objc, Tcl_Obj *const objv[])
{
    if (objc > 1) {
        int i = 1;
        char const *stri = Tcl_GetString (objv[i]);
        if (strcasecmp (stri, "help") == 0) {
            puts ("");
            puts ("  assemop [<address>] <opcode>...");
            puts ("   address = integer address of the opcode (for page-relative addresses)");
            puts ("    opcode = opcode string(s)");
            puts ("");
            return TCL_OK;
        }

        char *p;
        uint16_t address = strtoul (stri, &p, 0);
        if ((objc == 2) || (p == stri) || (*p != 0)) address = 0200;
                              else stri = Tcl_GetString (objv[++i]);

        std::string opstr;
        while (true) {
            opstr.append (stri);
            if (++ i >= objc) break;
            opstr.push_back (' ');
            stri = Tcl_GetString (objv[i]);
        }

        uint16_t opcode;
        char *err = assemble (opstr.c_str (), address, &opcode);
        if (err != NULL) {
            Tcl_SetResult (interp, err, (void (*) (char *)) free);
            return TCL_ERROR;
        }
        Tcl_SetObjResult (interp, Tcl_NewIntObj (opcode));
        return TCL_OK;
    }

    Tcl_SetResult (interp, (char *) "bad number of arguments", TCL_STATIC);
    return TCL_ERROR;
}

// disassemble instruciton
//  disasop opcode [address]
static int cmd_disasop (ClientData clientdata, Tcl_Interp *interp, int objc, Tcl_Obj *const objv[])
{
    int opcode = -1;
    int addr = 0200;

    switch (objc) {
        case 2: {
            char const *opstr = Tcl_GetString (objv[1]);
            if (strcasecmp (opstr, "help") == 0) {
                puts ("");
                puts ("  disasop <opcode> [<address>]");
                puts ("    opcode = integer opcode");
                puts ("   address = integer address of the opcode (for page-relative addresses)");
                puts ("");
                return TCL_OK;
            }
            int rc = Tcl_GetIntFromObj (interp, objv[1], &opcode);
            if (rc != TCL_OK) return rc;
            break;
        }
        case 3: {
            int rc = Tcl_GetIntFromObj (interp, objv[1], &opcode);
            if (rc == TCL_OK) rc = Tcl_GetIntFromObj (interp, objv[2], &addr);
            if (rc != TCL_OK) return rc;
            break;
        }
        default: {
            Tcl_SetResult (interp, (char *) "bad number of arguments", TCL_STATIC);
            return TCL_ERROR;
        }
    }

    std::string str = disassemble (opcode, addr);
    Tcl_SetResult (interp, strdup (str.c_str ()), (void (*) (char *)) free);
    return TCL_OK;
}

static int cmd_flushit (ClientData clientdata, Tcl_Interp *interp, int objc, Tcl_Obj *const objv[])
{
    switch (objc) {
        case 1: {
            if (pthread_mutex_lock (&padmutex) != 0) ABORT ();
            flushit ();
            rdpadsvalid = false;
            if (pthread_mutex_unlock (&padmutex) != 0) ABORT ();
            return TCL_OK;
        }
        case 2: {
            char const *swname = Tcl_GetString (objv[1]);
            if (strcasecmp (swname, "help") == 0) {
                puts ("");
                puts (" flushit");
                puts ("   flush pending writes to paddles");
                puts ("   invalidate cached paddle reads");
                puts ("");
                return TCL_OK;
            }
            break;
        }
    }
    Tcl_SetResult (interp, (char *) "bad number of arguments", TCL_STATIC);
    return TCL_ERROR;
}

// get gpio pin
static int cmd_getpin (ClientData clientdata, Tcl_Interp *interp, int objc, Tcl_Obj *const objv[])
{
    switch (objc) {
        case 2: {
            char const *regname = Tcl_GetString (objv[1]);
            if (strcasecmp (regname, "help") == 0) {
                puts ("");
                puts (" getpin <pinnumber>");
                puts ("   0.. 7 : U1 GPA0..7");
                puts ("   8..15 : U1 GPB0..7");
                puts ("  16..23 : U2 GPA0..7");
                puts ("  24..31 : U2 GPB0..7");
                puts ("  32..39 : U3 GPA0..7");
                puts ("  40..47 : U3 GPB0..7");
                puts ("  48..55 : U4 GPA0..7");
                puts ("  56..63 : U4 GPB0..7");
                puts ("  64..71 : U5 GPA0..7");
                puts ("  72..79 : U5 GPB0..7");
                puts ("");
                return TCL_OK;
            }
            int pinnum;
            int rc = Tcl_GetIntFromObj (interp, objv[1], &pinnum);
            if (rc != TCL_OK) return rc;
            if ((pinnum < 0) || (pinnum > 79)) {
                Tcl_SetResultF (interp, "bad pin number %d\n", pinnum);
                return TCL_ERROR;
            }
            int pinval = padlib->readpin (pinnum);
            if (pinval < 0) {
                Tcl_SetResultF (interp, "error reading pin %d\n", pinnum);
                return TCL_ERROR;
            }
            Tcl_SetObjResult (interp, Tcl_NewIntObj (pinval));
            return TCL_OK;
        }
    }
    Tcl_SetResult (interp, (char *) "bad number of arguments", TCL_STATIC);
    return TCL_ERROR;
}

// get register (lights)
static int cmd_getreg (ClientData clientdata, Tcl_Interp *interp, int objc, Tcl_Obj *const objv[])
{
    switch (objc) {
        case 2: {
            char const *regname = Tcl_GetString (objv[1]);
            if (strcasecmp (regname, "help") == 0) {
                puts ("");
                puts (" getreg <registername>");
                puts ("   multi-bit registers:");
                puts ("      ac - accumulator");
                puts ("      ir - instruction register 0..7");
                puts ("      ma - memory address");
                puts ("      mb - memory buffer");
                puts ("   state - which of F E D WC CA B are lit");
                puts ("   single-bit registers:");
                puts ("      ea - extended address");
                puts ("    link - link bit");
                puts ("     ion - interrupts enabled");
                puts ("     par - memory parity error");
                puts ("    prot - memory protect error");
                puts ("     run - executing instructions");
                puts ("");
                return TCL_OK;
            }
            int const *regpins = NULL;
            if (strcasecmp (regname, "ac") == 0) regpins = acbits;
            if (strcasecmp (regname, "ir") == 0) regpins = irbits;
            if (strcasecmp (regname, "ma") == 0) regpins = mabits;
            if (strcasecmp (regname, "mb") == 0) regpins = mbbits;
            if (regpins != NULL) {
                if (pthread_mutex_lock (&padmutex) != 0) ABORT ();
                int regval = getreg (regpins);
                if (pthread_mutex_unlock (&padmutex) != 0) ABORT ();
                Tcl_SetObjResult (interp, Tcl_NewIntObj (regval));
                return TCL_OK;
            }
            if (strcasecmp (regname, "state") == 0) {
                char *statebuf = (char *) malloc (16);
                if (statebuf == NULL) ABORT ();
                char *p = statebuf;
                if (pthread_mutex_lock (&padmutex) != 0) ABORT ();
                if (getpin (P_FET)) { strcpy (p, "F ");  p += strlen (p); }
                if (getpin (P_EXE)) { strcpy (p, "E ");  p += strlen (p); }
                if (getpin (P_DEF)) { strcpy (p, "D ");  p += strlen (p); }
                if (getpin (P_WCT)) { strcpy (p, "WC "); p += strlen (p); }
                if (getpin (P_CAD)) { strcpy (p, "CA "); p += strlen (p); }
                if (getpin (P_BRK)) { strcpy (p, "B ");  p += strlen (p); }
                if (pthread_mutex_unlock (&padmutex) != 0) ABORT ();
                if (p > statebuf) -- p;
                *p = 0;
                Tcl_SetResult (interp, statebuf, (void (*) (char *)) free);
                return TCL_OK;
            }
            int pinum = -1;
            if (strcasecmp (regname, "ea")   == 0) pinum = P_EMA;
            if (strcasecmp (regname, "ion")  == 0) pinum = P_ION;
            if (strcasecmp (regname, "link") == 0) pinum = P_LINK;
            if (strcasecmp (regname, "par")  == 0) pinum = P_PARE;
            if (strcasecmp (regname, "prot") == 0) pinum = P_PRTE;
            if (strcasecmp (regname, "run")  == 0) pinum = P_RUN;
            if (pinum >= 0) {
                if (pthread_mutex_lock (&padmutex) != 0) ABORT ();
                int regval = getpin (pinum);
                if (pthread_mutex_unlock (&padmutex) != 0) ABORT ();
                Tcl_SetObjResult (interp, Tcl_NewIntObj (regval));
                return TCL_OK;
            }
            Tcl_SetResultF (interp, "bad register name %s", regname);
            return TCL_ERROR;
        }
    }
    Tcl_SetResult (interp, (char *) "bad number of arguments", TCL_STATIC);
    return TCL_ERROR;
}

// get switch
static int cmd_getsw (ClientData clientdata, Tcl_Interp *interp, int objc, Tcl_Obj *const objv[])
{
    switch (objc) {
        case 2: {
            char const *swname = Tcl_GetString (objv[1]);
            if (strcasecmp (swname, "help") == 0) {
                puts ("");
                puts (" getsw <switchname>");
                for (int i = 0; permsws[i].name != NULL; i ++) {
                    printf ("      %s\n", permsws[i].name);
                }
                puts ("");
                return TCL_OK;
            }
            for (int i = 0; permsws[i].name != NULL; i ++) {
                if (strcasecmp (swname, permsws[i].name) == 0) {
                    int swval = 0;
                    if (pthread_mutex_lock (&padmutex) != 0) ABORT ();
                    for (int j = permsws[i].nbits; -- j >= 0;) {
                        swval <<= 1;
                        swval += getpin (permsws[i].pinums[j]);
                    }
                    if (pthread_mutex_unlock (&padmutex) != 0) ABORT ();
                    Tcl_SetObjResult (interp, Tcl_NewIntObj (swval));
                    return TCL_OK;
                }
            }
            Tcl_SetResultF (interp, "bad switch name %s", swname);
            return TCL_ERROR;
        }
    }
    Tcl_SetResult (interp, (char *) "bad number of arguments", TCL_STATIC);
    return TCL_ERROR;
}

// get library name
static int cmd_libname (ClientData clientdata, Tcl_Interp *interp, int objc, Tcl_Obj *const objv[])
{
    Tcl_SetResult (interp, (char *) padlib->libname (), TCL_STATIC);
    return TCL_OK;
}

// read character with timeout as an integer
// returns null string if timeout, else decimal integer
//  readchar file timeoutms
static int cmd_readchar (ClientData clientdata, Tcl_Interp *interp, int objc, Tcl_Obj *const objv[])
{
    if (objc == 3) {
        char const *stri = Tcl_GetString (objv[1]);
        if (memcmp (stri, "file", 4) != 0) {
            Tcl_SetResultF (interp, "first argument not a file");
            return TCL_ERROR;
        }
        int fd = atoi (stri + 4);
        int tmoms;
        int rc = Tcl_GetIntFromObj (interp, objv[2], &tmoms);
        if (rc != TCL_OK) return rc;
        struct pollfd fds = { fd, POLLIN, 0 };
        rc = poll (&fds, 1, tmoms);
        uint8_t buff;
        if (rc > 0) rc = read (fd, &buff, 1);
        if (rc < 0) {
            if (errno == EINTR) return TCL_OK;
            Tcl_SetResultF (interp, "%m");
            return TCL_ERROR;
        }
        if (rc > 0) Tcl_SetResultF (interp, "%u", (uint32_t) buff);
        return TCL_OK;
    }

    Tcl_SetResult (interp, (char *) "bad number of arguments", TCL_STATIC);
    return TCL_ERROR;
}

// set gpio pin
static int cmd_setpin (ClientData clientdata, Tcl_Interp *interp, int objc, Tcl_Obj *const objv[])
{
    switch (objc) {
        case 3: {
            char const *regname = Tcl_GetString (objv[1]);
            if (strcasecmp (regname, "help") == 0) {
                puts ("");
                puts (" setpin <pinnumber> <boolean>");
                puts ("   0.. 7 : U1 GPA0..7");
                puts ("   8..15 : U1 GPB0..7");
                puts ("  16..23 : U2 GPA0..7");
                puts ("  24..31 : U2 GPB0..7");
                puts ("  32..39 : U3 GPA0..7");
                puts ("  40..47 : U3 GPB0..7");
                puts ("  48..55 : U4 GPA0..7");
                puts ("  56..63 : U4 GPB0..7");
                puts ("  64..71 : U5 GPA0..7");
                puts ("  72..79 : U5 GPB0..7");
                puts ("");
                return TCL_OK;
            }
            int pinnum, pinval;
            int rc = Tcl_GetIntFromObj (interp, objv[1], &pinnum);
            if (rc != TCL_OK) return rc;
            if ((pinnum < 0) || (pinnum > 79)) {
                Tcl_SetResultF (interp, "bad pin number %d\n", pinnum);
                return TCL_ERROR;
            }
            rc = Tcl_GetBooleanFromObj (interp, objv[2], &pinval);
            if (rc != TCL_OK) return rc;
            if (! ((wrmsks[pinnum/16] >> (pinnum % 16)) & 1)) {
                pinval = -1;
            } else if (padlib->writepin (pinnum, pinval) < 0) {
                Tcl_SetResultF (interp, "error writing pin %d\n", pinnum);
                return TCL_ERROR;
            }
            Tcl_SetObjResult (interp, Tcl_NewIntObj (pinval));
            return TCL_OK;
        }
    }
    Tcl_SetResult (interp, (char *) "bad number of arguments", TCL_STATIC);
    return TCL_ERROR;
}
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

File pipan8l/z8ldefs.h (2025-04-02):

//    Copyright (C) Mike Rieker, Beverly, MA USA
//    www.outerworldapps.com
//
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
//    EXPECT it to FAIL when someone's HeALTh or PROpeRTy is at RISk.
//
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
//    http://www.gnu.org/licenses/gpl-2.0.html

// bits provided by pdp8l.v in the zynq

#ifndef _Z8LDEFS
#define _Z8LDEFS

#define Z_VER 0     // pdp8l.v version number
#define Z_RA 1      // contain the various bits
#define Z_RB 2
#define Z_RC 3
#define Z_RD 4
#define Z_RE 5
#define Z_RF 6
#define Z_RG 7
#define Z_RH 8
#define Z_RI 9
#define Z_RJ 10
#define Z_RK 11
#define Z_RL 12
#define Z_RM 13
#define Z_RN 14     // memcycctr
#define Z_RO 15
#define Z_RP 16
#define Z_RQ 17

#define Z_N 17      // total number of register

#define ZZ_RA (a_i_CA_INCRMNT | a_i_DATA_IN | a_i_MEM_P | a_i_EA | a_i_MEMDONE | a_i_STROBE | a_i_B36V1 | a_i_D36B2)
#define ZZ_RC (c_i_MEM)
#define ZZ_RD 0

#define a_iBEMA        (1U <<  0)
#define a_i_CA_INCRMNT (1U <<  1)
#define a_i_DATA_IN    (1U <<  2)
#define a_iMEMINCR     (1U <<  3)
#define a_i_MEM_P      (1U <<  4)
#define a_i3CYCLE      (1U <<  5)
#define a_iAC_CLEAR    (1U <<  6)
#define a_iBRK_RQST    (1U <<  7)
#define a_i_EA         (1U <<  8)
#define a_iEMA         (1U <<  9)
#define a_iINT_INHIBIT (1U << 10)
#define a_iINT_RQST    (1U << 11)
#define a_iIO_SKIP     (1U << 12)
#define a_i_MEMDONE    (1U << 13)
#define a_i_STROBE     (1U << 14)
#define a_i_B36V1      (1U << 15)
#define a_i_D36B2      (1U << 16)

#define b_swCONT        (1U <<  0)
#define b_swDEP         (1U <<  1)
#define b_swDFLD        (1U <<  2)
#define b_swEXAM        (1U <<  3)
#define b_swIFLD        (1U <<  4)
#define b_swLDAD        (1U <<  5)
#define b_swMPRT        (1U <<  6)
#define b_swSTEP        (1U <<  7)
#define b_swSTOP        (1U <<  8)
#define b_swSTART       (1U <<  9)
#define b_swSR      (07777U << 20)

#define c_iINPUTBUS (07777U <<  0)
#define c_i_MEM     (07777U << 16)
#define d_iDMAADDR  (07777U <<  0)
#define d_iDMADATA  (07777U << 16)

#define e_simit         (1U <<  0)  //rw 0=real PDP-8/L; 1=pdp8lsim.v
#define e_fpgareset     (1U <<  1)  //rw 0=normal; 1=power-on-reset
#define e_nanocontin    (1U <<  2)  //rw 0=single step mode (sim only); 1=normal continuous running
#define e_nanotrigger   (1U <<  3)  //rw 0=ignored; 1=trigger single step (sim only)
#define e_nanocstep     (1U <<  4)  //ro 0=stopped; 1=stepping
#define e_bareit        (1U <<  6)  //rw 0=pass device data to PDP-8/L & sim 'i' pins
                                    //   1=pass arm reg data to PDP-8/L & sim 'i' pins

#define f_oBIOP1         (1U <<  0)
#define f_oBIOP2         (1U <<  1)
#define f_oBIOP4         (1U <<  2)
#define f_oBTP2          (1U <<  3)
#define f_oBTP3          (1U <<  4)
#define f_oBTS_1         (1U <<  5)
#define f_oBTS_3         (1U <<  6)
#define f_oC36B2         (1U <<  7)
#define f_o_BWC_OVERFLOW (1U <<  8)
#define f_o_B_BREAK      (1U <<  9)
#define f_oE_SET_F_SET   (1U << 10)
#define f_oJMP_JMS       (1U << 11)
#define f_oLINE_LOW      (1U << 12)
#define f_oMEMSTART      (1U << 13)
#define f_o_ADDR_ACCEPT  (1U << 14)
#define f_o_BF_ENABLE    (1U << 15)
#define f_o_BUSINIT      (1U << 16)
#define f_oB_RUN         (1U << 17)
#define f_o_DF_ENABLE    (1U << 18)
#define f_o_KEY_CLEAR    (1U << 19)
#define f_o_KEY_DF       (1U << 20)
#define f_o_KEY_IF       (1U << 21)
#define f_o_KEY_LOAD     (1U << 22)
#define f_o_LOAD_SF      (1U << 23)
#define f_o_SP_CYC_NEXT  (1U << 24)
#define f_oD35B2         (1U << 25)
#define f_didio          (1U << 26)

#define g_lbBRK         (1U <<  0)
#define g_lbCA          (1U <<  1)
#define g_lbDEF         (1U <<  2)
#define g_lbEA          (1U <<  3)
#define g_lbEXE         (1U <<  4)
#define g_lbFET         (1U <<  5)
#define g_lbION         (1U <<  6)
#define g_lbLINK        (1U <<  7)
#define g_lbRUN         (1U <<  8)
#define g_lbWC          (1U <<  9)
#define g_debounced     (1U << 10)
#define g_lastswLDAD    (1U << 11)
#define g_lastswSTART   (1U << 12)
#define g_simmemen      (1U << 13)
#define g_lbPRTE        (1U << 14)
#define g_lbIR          (7U << 25)

#define h_oBAC      (07777U <<  0)
#define h_oBMB      (07777U << 16)
#define i_oMA       (07777U <<  0)
#define i_lbAC      (07777U << 16)
#define j_lbMA      (07777U <<  0)
#define j_lbMB      (07777U << 16)

#define k_majstate  (  017U <<  0)
#define k_timedelay (  077U <<  4)
#define k_timestate (  037U << 10)
#define k_cyclectr  (01777U << 15)
#define k_nextmajst (  017U << 25)

#define l_xbraddr  (077777U <<  0)
#define l_xbrwena  (     1U << 16)
#define l_xbrenab  (     1U << 20)
#define l_meminprog (01777U << 22)
#define m_xbrrdat  ( 07777U <<  0)
#define m_xbrwdat  ( 07777U << 16)
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

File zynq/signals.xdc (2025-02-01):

set_property PACKAGE_PIN W16 [get_ports bDMABUSA_0]
set_property IOSTANDARD LVCMOS33 [get_ports bDMABUSA_0]
set_property PACKAGE_PIN R17 [get_ports bDMABUSB_0]
set_property IOSTANDARD LVCMOS33 [get_ports bDMABUSB_0]
set_property PACKAGE_PIN Y19 [get_ports bDMABUSC_0]
set_property IOSTANDARD LVCMOS33 [get_ports bDMABUSC_0]
set_property PACKAGE_PIN U20 [get_ports bDMABUSD_0]
set_property IOSTANDARD LVCMOS33 [get_ports bDMABUSD_0]
set_property PACKAGE_PIN P19 [get_ports bDMABUSE_0]
set_property IOSTANDARD LVCMOS33 [get_ports bDMABUSE_0]
set_property PACKAGE_PIN V15 [get_ports bDMABUSF_0]
set_property IOSTANDARD LVCMOS33 [get_ports bDMABUSF_0]
set_property PACKAGE_PIN V16 [get_ports bDMABUSH_0]
set_property IOSTANDARD LVCMOS33 [get_ports bDMABUSH_0]
set_property PACKAGE_PIN R16 [get_ports bDMABUSJ_0]
set_property IOSTANDARD LVCMOS33 [get_ports bDMABUSJ_0]
set_property PACKAGE_PIN Y18 [get_ports bDMABUSK_0]
set_property IOSTANDARD LVCMOS33 [get_ports bDMABUSK_0]
set_property PACKAGE_PIN T20 [get_ports bDMABUSL_0]
set_property IOSTANDARD LVCMOS33 [get_ports bDMABUSL_0]
set_property PACKAGE_PIN N18 [get_ports bDMABUSM_0]
set_property IOSTANDARD LVCMOS33 [get_ports bDMABUSM_0]
set_property PACKAGE_PIN T15 [get_ports bDMABUSN_0]
set_property IOSTANDARD LVCMOS33 [get_ports bDMABUSN_0]
set_property PACKAGE_PIN Y7 [get_ports bFPI2CDATA_0]
set_property IOSTANDARD LVCMOS33 [get_ports bFPI2CDATA_0]
set_property PACKAGE_PIN F20 [get_ports bMEMBUSA_0]
set_property IOSTANDARD LVCMOS33 [get_ports bMEMBUSA_0]
set_property PACKAGE_PIN N16 [get_ports bMEMBUSB_0]
set_property IOSTANDARD LVCMOS33 [get_ports bMEMBUSB_0]
set_property PACKAGE_PIN M15 [get_ports bMEMBUSC_0]
set_property IOSTANDARD LVCMOS33 [get_ports bMEMBUSC_0]
set_property PACKAGE_PIN K16 [get_ports bMEMBUSD_0]
set_property IOSTANDARD LVCMOS33 [get_ports bMEMBUSD_0]
set_property PACKAGE_PIN K14 [get_ports bMEMBUSE_0]
set_property IOSTANDARD LVCMOS33 [get_ports bMEMBUSE_0]
set_property PACKAGE_PIN G19 [get_ports bMEMBUSF_0]
set_property IOSTANDARD LVCMOS33 [get_ports bMEMBUSF_0]
set_property PACKAGE_PIN J20 [get_ports bMEMBUSH_0]
set_property IOSTANDARD LVCMOS33 [get_ports bMEMBUSH_0]
set_property PACKAGE_PIN M14 [get_ports bMEMBUSJ_0]
set_property IOSTANDARD LVCMOS33 [get_ports bMEMBUSJ_0]
set_property PACKAGE_PIN J16 [get_ports bMEMBUSK_0]
set_property IOSTANDARD LVCMOS33 [get_ports bMEMBUSK_0]
set_property PACKAGE_PIN L15 [get_ports bMEMBUSL_0]
set_property IOSTANDARD LVCMOS33 [get_ports bMEMBUSL_0]
set_property PACKAGE_PIN G20 [get_ports bMEMBUSM_0]
set_property IOSTANDARD LVCMOS33 [get_ports bMEMBUSM_0]
set_property PACKAGE_PIN G18 [get_ports bMEMBUSN_0]
set_property IOSTANDARD LVCMOS33 [get_ports bMEMBUSN_0]
set_property PACKAGE_PIN T12 [get_ports bPIOBUSA_0]
set_property IOSTANDARD LVCMOS33 [get_ports bPIOBUSA_0]
set_property PACKAGE_PIN V12 [get_ports bPIOBUSB_0]
set_property IOSTANDARD LVCMOS33 [get_ports bPIOBUSB_0]
set_property PACKAGE_PIN P14 [get_ports bPIOBUSC_0]
set_property IOSTANDARD LVCMOS33 [get_ports bPIOBUSC_0]
set_property PACKAGE_PIN M17 [get_ports bPIOBUSD_0]
set_property IOSTANDARD LVCMOS33 [get_ports bPIOBUSD_0]
set_property PACKAGE_PIN F17 [get_ports bPIOBUSE_0]
set_property IOSTANDARD LVCMOS33 [get_ports bPIOBUSE_0]
set_property PACKAGE_PIN D19 [get_ports bPIOBUSF_0]
set_property IOSTANDARD LVCMOS33 [get_ports bPIOBUSF_0]
set_property PACKAGE_PIN U12 [get_ports bPIOBUSH_0]
set_property IOSTANDARD LVCMOS33 [get_ports bPIOBUSH_0]
set_property PACKAGE_PIN W13 [get_ports bPIOBUSJ_0]
set_property IOSTANDARD LVCMOS33 [get_ports bPIOBUSJ_0]
set_property PACKAGE_PIN W14 [get_ports bPIOBUSK_0]
set_property IOSTANDARD LVCMOS33 [get_ports bPIOBUSK_0]
set_property PACKAGE_PIN M18 [get_ports bPIOBUSL_0]
set_property IOSTANDARD LVCMOS33 [get_ports bPIOBUSL_0]
set_property PACKAGE_PIN F16 [get_ports bPIOBUSM_0]
set_property IOSTANDARD LVCMOS33 [get_ports bPIOBUSM_0]
set_property PACKAGE_PIN D20 [get_ports bPIOBUSN_0]
set_property IOSTANDARD LVCMOS33 [get_ports bPIOBUSN_0]
set_property PACKAGE_PIN V20 [get_ports i_B36V1_0]
set_property IOSTANDARD LVCMOS33 [get_ports i_B36V1_0]
set_property PACKAGE_PIN V10 [get_ports i_CA_INCRMNT_0]
set_property IOSTANDARD LVCMOS33 [get_ports i_CA_INCRMNT_0]
set_property PACKAGE_PIN T11 [get_ports i_D36B2_0]
set_property IOSTANDARD LVCMOS33 [get_ports i_D36B2_0]
set_property PACKAGE_PIN T10 [get_ports i_DATA_IN_0]
set_property IOSTANDARD LVCMOS33 [get_ports i_DATA_IN_0]
set_property PACKAGE_PIN U17 [get_ports i_EA_0]
set_property IOSTANDARD LVCMOS33 [get_ports i_EA_0]
set_property PACKAGE_PIN B20 [get_ports i_FPI2CDENA_0]
set_property IOSTANDARD LVCMOS33 [get_ports i_FPI2CDENA_0]
set_property PACKAGE_PIN U15 [get_ports i_MEM_07_0]
set_property IOSTANDARD LVCMOS33 [get_ports i_MEM_07_0]
set_property PACKAGE_PIN U18 [get_ports i_MEMDONE_0]
set_property IOSTANDARD LVCMOS33 [get_ports i_MEMDONE_0]
set_property PACKAGE_PIN Y8 [get_ports iMEMINCR_0]
set_property IOSTANDARD LVCMOS33 [get_ports iMEMINCR_0]
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

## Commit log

2024-11-25 initial files for I2C-based console using a RasPI-Zero-W
    also can connect the RasPI-Zero-W to a ZTurn for testing
    uses the enclosed pdp8v/zynq vivado project for zync code
    [pipanel.kicad_pcb, pipanel.kicad_sch]
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2024-11-25 have PDP-8/V Zynq frontpanel.v exam switch not increment unless used twice in a row
    ...so it's more like PDP-8/L
2024-11-25 add ttpanel to display lamp and switch states continuously
    uses udp to inquire state from pipanel
2024-11-25 highlight active lights a little better with bold red
    also use pipanel 'setsw sr' for pdp8v switchregister
2024-11-25 updates to ttpanel
    default ttpanel ipaddress to 127.0.0.1
    update ttpanel to display frames-per-second
    change mprot -> mprt to be consistent everywhere
2024-11-25 add IOT opcode to assembler
    follow it with a number in range 06000..06777
2024-11-25 add looptest command to testmem.tcl and count errors
    looptest testzeroes
    loops the testzeroes case
    and breaks it into steps of 040 words
2024-11-25 rename pipanel to pipan8l and reference pdp8v github branch
    [pipan8l.kicad_pcb, pipan8l.kicad_sch]
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2024-11-25 add missing notitleblock.kicads_wks file and new simming.txt
2024-11-25 attempt to get zynq /dev/i2c-0 working
    ...gets occasional timeout errors
    [i2clib.cc]
2024-11-25 few small script changes
    - add steploop command to single step, dump, prompt for enter to step again
    - ignore EA bit when writing memory cuz there's no extended memory
    - turn off all switches on startup
    - can have testrands test use address bits in reverse to test upper address bits
2024-11-25 add z8llib.cc code to access the zturn pdp-8/l backend test code
    also has small fixes for readprompt flushing prompt
    program zturn with ../zynq
    run using z8l.sh that loads zynqgpio page module
    [pipan8l.cc]
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2024-11-25 add pdp8ltty.v module - not working
    [pdp8l.v]
2024-11-25 add z8ldump, z8ltty programs
    - used with zturn/zynq io board plugged into slots 34,35,36
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2024-11-25 get most of z8lrand working
    ...it just fails when testing random tty io opcodes
    [pdp8l.v]
2024-11-25 add testioins control bit so z8lrand can test io instructions
    ...without engaging io boards like the tty
2024-11-25 add testioins control bit so z8lrand can test io instructions
    also print simulated instruction time
    and remove usleep()s
    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
2024-11-25 fix up interrupt enable / disable instruction processing
    [pdp8l.v]
2024-11-25 add interrupt enable and request handling to z8lrand
    ...but interrupt request doesn't work
    [z8ldefs.h]
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2024-11-25 add businit vs poweronreset circuit and xmem support for load address
    - poweronreset resets everything
    - businit only resets things for the start switch
    [pdp8lrk8je.v, pdp8lsim.v, pdp8lxmem.v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]
2024-11-25 fix driver mapping of whole 32K memory at once
    update extmemtest to compare extmemptr access vs xmem access
    [z8ldefs.h]
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2024-11-25 make tty interrupt enabled by default for maindec D02B
    also shorten extmem read to 3 cycles instead of 4
    [extmemmap.v]
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2024-11-25 get all mixes of z8lcmemtest brkwhenhltd/externlow4k/manualclock working
    had to latch EA bit at beginning of TS1 like real PDP-8/L mem enable flipflop
    [pdp8lsim.v, zynq.v]
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2024-11-25 always use cmem for dma writes so processor doesn't overwrite the dma
    example of why extmem doesn't work:
    rk05 boot sequence:
    processor does TS1 of the 0031 JMP 0031 instruction
    z8lrk8je writes JMP 0030 to address 0031 via extmem[]
    processor does TS3 of the 0031 JMP 0031 instruction, writing the JMP 0031 back
    ...so the JMP 0030 is overwritten and the boot hangs
    using cmem writes the JMP 0030 via BREAK cycle so won't get overwritten
2024-11-25 fix up cmem lock to require write matching non-zero value to unlock
    [pdp8lcmem.v]
2024-11-25 stop and reset cpu before spawning z8ltty when running diagnostics
    ...so previous stuff left in tty register will not mess it up
    [z8ldefs.h]
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2024-11-25 hold pdp8lsim.v in reset if using real pdp
    [zynq.v]
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2024-11-25 have findev() print its own error message and never return NULL
2024-11-25 enable io devices by default during power-on reset
    so tty and others won't lose initial ios on startup
    [pdp8lrk8je.v, pdp8lxmem.v, zynq.v]
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2024-11-25 support os8zap in pdp8lxmem.v
    also fix z8lsimtest.cc to skip io opcode for devices
    ...only generate io opcodes 600x and 62xx
    [z8ldefs.h]
2024-11-25 fix up iszloop.tcl script for testing os8zap
    and remove some debug prints
2024-11-25 add zturn circuit boards
    3 boards plug in back 3 slots of PDP-8/L
    zturn34 - slot 34 B,C,D
    zturn35 - slot 35 B,C,D
    zturn36 - slot 36 B,C,D
    plus interconnect board zturnic
    [signals.ods, zturn34.kicad_pcb, zturn34.kicad_sch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]
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2024-11-27 fix some bus pin mapping
    [signals.ods]
2024-11-28 update zturn34,35 pcbs - move 10uF caps, add fiducials
    [zturn34.kicad_pcb, zturn34.kicad_sch, zturn35.kicad_pcb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]
2024-11-29 split zturn34 board into zturn34b and zturn34d
    [zturn34.kicad_pcb, zturn34.kicad_sch, zturn34b.kicad_pcb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]
2024-11-29 add schematic for tty usb adapter
    [ttyusbpcb.kicad_pcb, ttyusbpcb.kicad_sch]
2024-11-30 put signals.csv insted of signals.ods in repo
    it is used by other scripts and can be edited with just as well as signals.ods
    [signals.csv, signals.ods]
2024-12-01 add -stopon option to z8ltty run command
    also make sure it doesn't print same char twice on
    stopping z8ltty and restarting z8ltty
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2024-12-10 convert oB_BREAK to o_B_BREAK cuz it's active low
    also end break cycle with end of TS3 instead of ADDR_ACCEPT cuz it's just a blip
    [signals.csv]
2024-12-10 convert iTHREECYCLE to i_3CYCLE cuz it's active low
    [signals.csv]
2024-12-12 get dma to real PDP-8/L core memory working
    * add z8ldmaloop program to generate continuous read dma address 0
    * fix z8lcmemtest to enable FPGA 100MHz clock when not simulating
    * MEMINCR signal is active low
    * sample DMA read data at end of TS3
    MB data comes valid ~50nS after beginning of TS3 and stays to beginning of next TS3
    [signals.csv]
2024-12-13 get most of PIO working
    on pipan8l or lightbulb/switch panel:
    set up 5252: JMP . and start it running
    on zturn:
    ./z8lreal
    ./z8lpiotest
    INT_RQST doesn't work
    BUSINIT is messed up so commented out
    [signals.csv]
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2024-12-13 get businit working
    ...both are active high
    [signals.csv]
2024-12-14 oBWC_OVERFLOW is active low => o_BWC_OVERFLOW
    ...and sample it 140nS into TS3
    [signals.csv]
2024-12-14 get z8lcmemtest -3cycle working reliably
    ./z8lcmemtest -3cycle
    ./z8lcmemtest -3cycle -cainc
    PDP doesn't respond well requesting BRK cycle in middle of TS1
    so request it in TS3 so as to be well-spaced from TS1
    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
    [pdp8lcmem.v, zynq.v]
2024-12-16 fix fpga power-on reset state and memory cycle counter
    have it power-on to not jam-up pdp busses
    [zynq.v]
2024-12-17 add M906 replacement board
    - populate with 1K resistors and replace the 4 M906s in the PDP-8/L
    original M906 has 220 resistors requiring 20mA from the 74AXP4T245 chips
    [ztm906.kicad_pcb, ztm906.kicad_sch]
2024-12-19 send out iMEM bus mem data only when using extended memory
    ...so membus can't jam up the MEM bus when reading PDP core memory
    [zynq.v]
2024-12-20 update signals.csv and zynq.v active low signals
    no code changes, just a little organizing
    [signals.csv]
2024-12-21 get external memory interface working
    * fix some broken pin assignments in signals.csv and .xdc
    * i_BEMA is active low
    * fix memory cycle i_STROBE and i_MEMDONE pulses
    and timing of r_MA,x_MEM bus multiplexing
    (see pdp8lxmem.v)
    test with:
    ./z8lcmemtest -extmem
    -3cycle is broken
    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
    [signals.csv]
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2024-12-24 fix pdp8lsim.v to work with pdp8lxmem.v that works with real PDP-8/L
    test with
    ./z8lsimtest
    ./z8lsim run-d01b.tcl
    ./z8lsim run-d02b.tcl
    ./z8lsim run-d04b.tcl
    ./z8lsim run-d05b.tcl
    ./z8lsim run-d1eb.tcl
    ./z8lsim run-d1gb.tcl
    [pdp8lsim.v, z8ldefs.h, zynq.v]
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2024-12-24 zynq: get enlo4k memory working with real PDP
    enlo4k didn't work with console-initiated memory cycles
    make a memory controller that mimics the real PDP's memory controller
    ...that doesn't rely on TS1 and TS3 signals
    [pdp8lxmem.v, z8ldefs.h, zynq.v]
2024-12-25 fix extmem controller to maintain original read data through end of cycle
    defer depends on original data through TS4 for autoincrement
    gets incremented in TS2 and written back to memory in TS3
    then get incremented again in TS4 and written to MA
    [pdp8lxmem.v]
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2025-01-16 use transistors for bus drivers instead of chips
    to handle the 180 & 220-ohm pullups
    [zturn34d.kicad_pcb, zturn34d.kicad_sch, zturn35.kicad_pcb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]
2025-01-16 update net names on zturn pcbs to match active high/low signal type
    [signals.csv, zturn34b.kicad_pcb, zturn34b.kicad_sch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]
2025-01-16 update software and further updates to firmware/pcbs
    ...for invertering transistors
    ./z8lsimtest works
    [signals.csv, zturn34b.kicad_pcb, zturn34b.kicad_sch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]
2025-01-16 fixed polarity of bus signals for the open-drain transistors
    PDP Zynq
    MEM _MEM
    MEM_P _MEM_P
    _DMAADDR DMAADDR
    _DMADATA DMADATA
    _INPUTBUS INPUTBUS
    Also fixed MEMINCR polarity and fixed missing ground connection on circuit board.
    [signals.csv, zturn34b.kicad_pcb, zturn34b.kicad_sch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]
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2025-01-16 update signals and zturn pcbs with pullups
    [signals.csv, zturn34d.kicad_sch, zturn35.kicad_pcb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]
2025-01-16 add I2C circuit to zturn boardset to operate front panel board
    [pipan8l.kicad_pcb, pipan8l.kicad_sch, zturn34d.kicad_pcb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]
2025-01-16 add pipan8l/pcb3
    plugs onto backplane - can sense lights and override panel switches
    does not sense AC, MA, MB, BREAK, RUN - they are available to zturn
    [pipan8l.kicad_pcb, pipan8l.kicad_sch]
2025-01-16 add pipan8l/pcb3x and little updates for pcb3
    pcb3 - plugs into backplane for console access with console in place
    pcb3x - backplane pin straightener/insulator/spacer for use with pcb3
    [pipan8l.kicad_pcb, pipan8l.kicad_sch]
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2025-01-16 get rid of z8llib.cc - pipan8l -z8l replaced by z8lpanel
    [i2clib.cc, pipan8l.cc]
2025-01-16 add front panel i2c pins to fpga source
    [signals.csv]
2025-01-16 fix up zynq i2c code not working yet
    [i2cmaster.v, i2czlib.cc, i2cztest.cc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]
2025-01-16 add clipping diodes to i2c bus for zynq-connected front panel
    also add _RESET line as 4th pin on connector
    [pipan8l.kicad_pcb, pipan8l.kicad_sch]
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2025-01-16 update pipan8l pcb3 reset circuit
    hold clock low for 1mS to trigger reset
    do not need 4th wire though pins are still there
    [pipan8l.kicad_pcb, pipan8l.kicad_sch]
2025-01-16 rename pipan8l pcb3 to z8lfpan - it is for use with zynq stuff
    [z8lfpan.kicad_pcb, z8lfpan.kicad_sch]
2025-01-16 add i2cztest2 program
    dumps out switches and lights as sensed on the pins
    also start fixing up i2czlib stuff but not done yet
    [i2czlib.cc, i2cztest.cc]
2025-01-16 fix zynq pin definitions to match new zturn34,35,36 boards
    [signals.csv]
2025-01-16 fix hizmembus blocking loading MA at beginning of mem cycle
    [pdp8lxmem.v, zynq.v]
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2025-01-16 fix hizmembus while reading memory and make iMEMINCR active high
    at this point:
    looptest testrands works on core and fpga memory
    cmemtest works on fpga memory
    [signals.csv, zturn36.kicad_pcb, zturn36.kicad_sch]
2025-01-16 get irq line working by fixing polarity
    ./z8lpiotest works now
    [zynq.v]
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2025-01-17 get rid of unneeded pipan8l/pcb2
    superceded by pcb3
    [pipan8l.kicad_pcb, pipan8l.kicad_sch]
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2025-01-22 reset the i* signals on softreset
    [zynq.v]
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2025-01-25 add pdp8lshad.v shadow and a reset program
    [pdp8lshad.v, pdp8lsim.v, zynq.v]
2025-01-26 fix false trigger for shadow
    - update local copy of AC at end of each io pulse
    - also add clearit bit to pdp8lshad to clear it
    [cmd_pin.cc, pdp8lshad.v, pdp8lxmem.v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]
2025-01-26 remove z8lshadow from makefile
    just use z8lpanel 'pin set sh_clearit 1' to reset the shadow module
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2025-01-29 add 'freeze-on-error' bit to pdp8lshad.v
    stops the processor if there is a mismatch
    start these two programs on reboot:
    ./z8lpanel -status server > statusserver.log 2>&1 &
    ./shadilaloop.sh > ~/ila.`date +%d%H%M%S` 2>&1 &
    may need to monitor ~/ila... file with tail -f
    ...especially when starting/stopping processor
    [cmd_pin.cc, pdp8lshad.v, pdp8lsim.v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]
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2025-02-01 have i2c use open-collector clock bus and fix stop bit for read function
    if reading a byte followed by reading another byte, send the ack bit
    if reading a byte followed by something else, omit ack bit
    if followed by a stop, the stop bit will be filled in where the ack was
    likewise for restart bit
    ...so stop or restart bit won't be overpowered by the next byte's data bit
    [i2cmaster.v, pdp8lfpi2c.v, signals.xdc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]
2025-02-01 update zturn36,35 pcbs to put i2c at 3.3V and open-collector
    ...directly from FPGA pins with 2.2K pullups
    [zturn35.kicad_pcb, zturn35.kicad_sch, zturn36.kicad_pcb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]
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2025-02-01 get i2c panel working with zynq and remove old raspi stuff
    - add lock cell to pdp8lfpi2c.v to synchronize access to i2c bus
    - remove udp code that accesses front panel via raspi
    - change i2cztest to use random numbers instead of sequential
    - remove redundant udp code from z8lpanel, just do -status on zturn itself
    - have i2cmaster.v send nak bit instead of leaving ack bit out on reads
    - have zynq.v turn on nanocontin on reset so clock runs by default
    [cmd_pin.cc, i2cmaster.v, i2czlib.cc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]
2025-02-01 butchered in 2N3904 in place of 74AXP4T245 for i_EA line
    don't know why the '245 didn't convert the signal
    so using a 2N3904 (PDP has a 1.8K pullup for that line)
    [zynq.v]
2025-02-04 update zturn34b pcb legend and clean up some traces
    fixed the i_EA driver output enable dec 26, but legend not updated
    [zturn34b.kicad_pcb]
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2025-02-05 find out how much extended memory cycles can be sped up
    the real PDP-8/L will run at approx 900nS
    z8lpanel:
    hardreset reset everything
    pin set xm_enlo4k 1 force all memory accesses to fpga ram
    fastxmem speed up fpga ram cycles
    [pdp8lxmem.v]
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2025-02-22 modify music.pal to use 'iszac' i/o opcode so timing loop works better
    opcode 6004 does increment AC and skip if zero via pdp8lpbit.v
    original loop was based on 6uS timing
    pdp-8/l takes 4.25uS for an I/O instruction leaving only 1.75uS
    ...so the ISZAC I/O instruction is used to get the timing right
    also has nice blikenlights effect as the AC is non-zero while playing
    [zynq.v]
2025-02-22 undo previous ZTURN34B board patch that inverted i_EA
    have updated 2025-02-04 board installed finally
    [zynq.v]
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2025-02-26 put 2024-12-30 version of zturn35,36 boards back
    the 2024-12-30 design had 5V I2C bus via 74AXP245s
    the newer boards had 3.3V I2C bus directly on FPGA
    the old boards work perfectly fine so go back to them
    ...rather than make new boards
    [zturn35.kicad_pcb, zturn35.kicad_sch, zturn36.kicad_pcb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]
2025-02-26 revert pipan8l/pcb3 front-panel piggy-back board to 2025-01-02
    it is good enough as is and don't want to make new boards
    [pipan8l.kicad_pcb, pipan8l.kicad_sch]
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2025-02-28 support for PDP-8/L without BREAK option installed
    performs DMA operations in the FPGA itself to its internal 32KW memory
    cannot access PDP-8/L's core memory, so requires -enlo4k option
    turn it on and reset FPGA:
    ./z8lreal -enlo4k -nobrk
    can also enable with z8lpanel command:
    ./z8lpanel -enlo4k -nobrk
    for simulation:
    ./z8lsim -enlo4k -nobrk
    tcl commands for z8lpanel, z8lsim:
    pin set cm_nobrk 1 0r 0
    pin set xm_enlo4k 1 or 0
    [cmd_pin.cc, i2czlib.cc, pdp8lcmem.v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]
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2025-03-07 add another factor to kaleid.pal
    flip the X axis every 3 cycles
    ...so the symmetry diagonal flips
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2025-03-11 add z8lpanel (pcb4) to repo - small strip front panel
    [z8lpanel.kicad_pcb, z8lpanel.kicad_sch]
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2025-03-20 update z8lpanel help text
    -status no longer has a hostname arg, it only works locally
    [z8lpanel.cc]
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2025-03-22 add photos of thin front-panel piggy back board
    got sides mixed up - a lot of the legends are on the wrong side
    but otherwise board works, just make sure you match photos when
    assembling, ie, the Z8LPANEL legend goes toward backplane pins,
    and the 3-pin I2C connector goes on the opposite side as the legend
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2025-12-24 don't reset I2C master when resetting FPGA
    so it doesn't jam up when resetting
    [zynq.v]

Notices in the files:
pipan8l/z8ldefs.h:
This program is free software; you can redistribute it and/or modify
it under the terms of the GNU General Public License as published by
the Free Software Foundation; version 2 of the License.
